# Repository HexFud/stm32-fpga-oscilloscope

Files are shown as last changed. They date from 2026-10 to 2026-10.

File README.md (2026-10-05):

# stm32-fpga-oscilloscope
I created a 1-Channel 20MHz 100MS/s Mixed-Signal Digital Storage Oscilloscope on a custom 4-layer PCB. Powered by STM32H7, Lattice iCE40 FPGA, and USB-C from scratch!

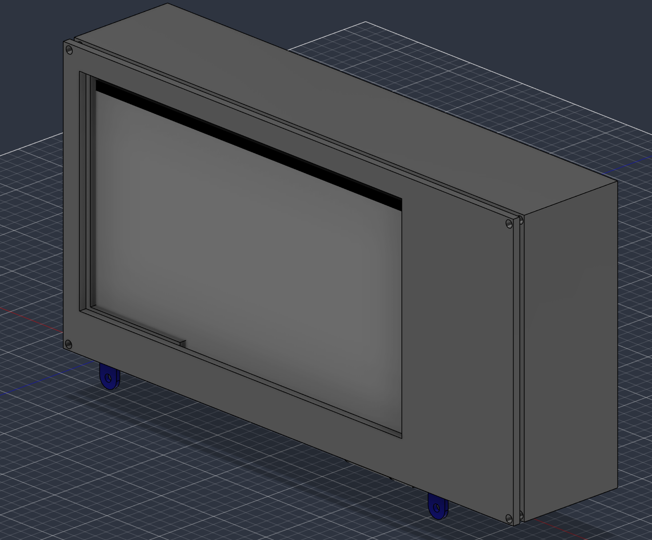
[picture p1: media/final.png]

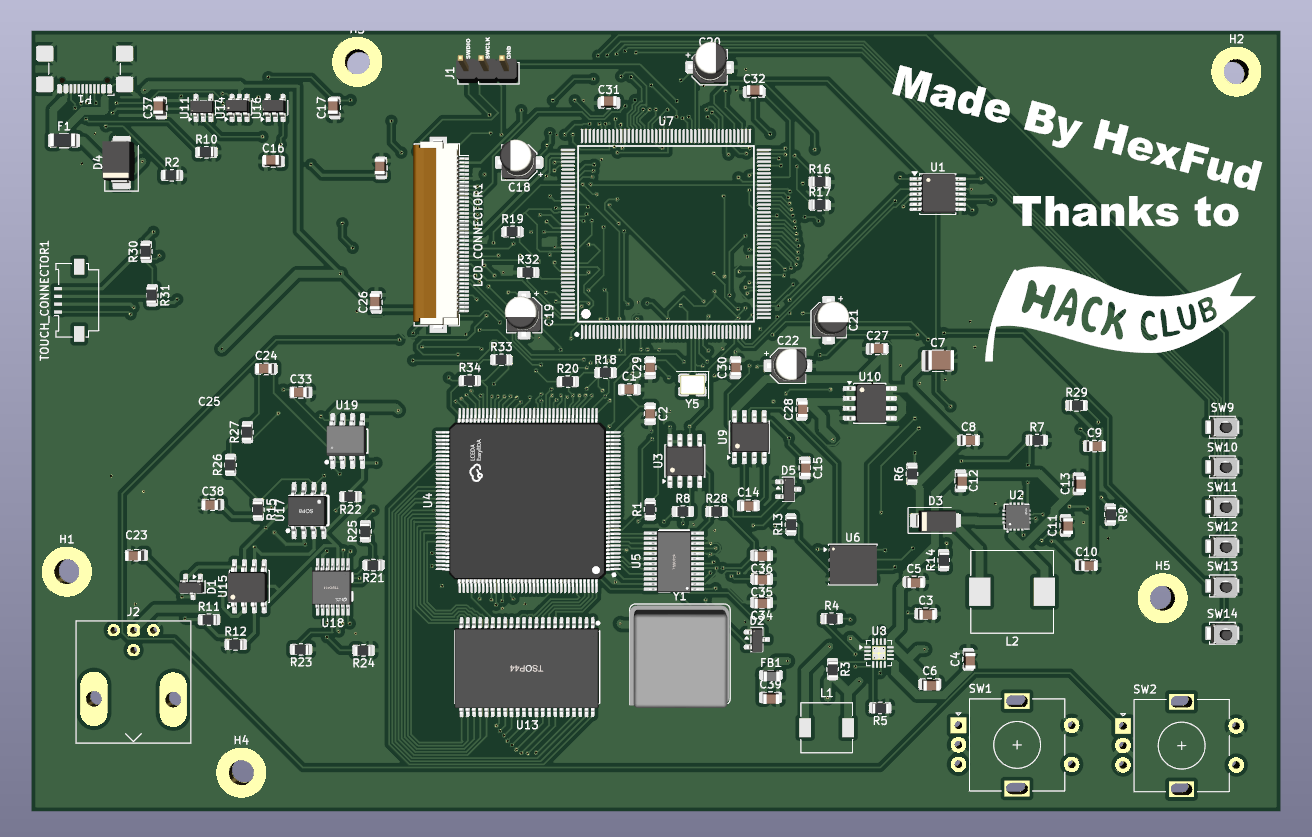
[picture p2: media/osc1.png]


## Project overview

The project is made of three parts that were designed together, because each one constrains the others: the PCB decides what the firmware can do, and the heat generated on the PCB decides how the enclosure is built.

| Part | What it covers | Tools |
| :--- | :--- | :--- |
| **PCB** | Schematic and 4-layer layout (see [Schematic and Routing](#schematic-and-routing) and [How this was made](#how-this-was-made)) | KiCad |
| **Firmware** | Acquisition, trigger, signal processing, waveform rendering and UI (see [Firmware](#firmware) and [Firmware architecture](#firmware-architecture)) | STM32CubeIDE, STM32 HAL |
| **CAD** | 3D-printable enclosure (see [Enclosure (CAD)](#enclosure-cad)) | **TODO:** CAD software |

## Schematic and Routing

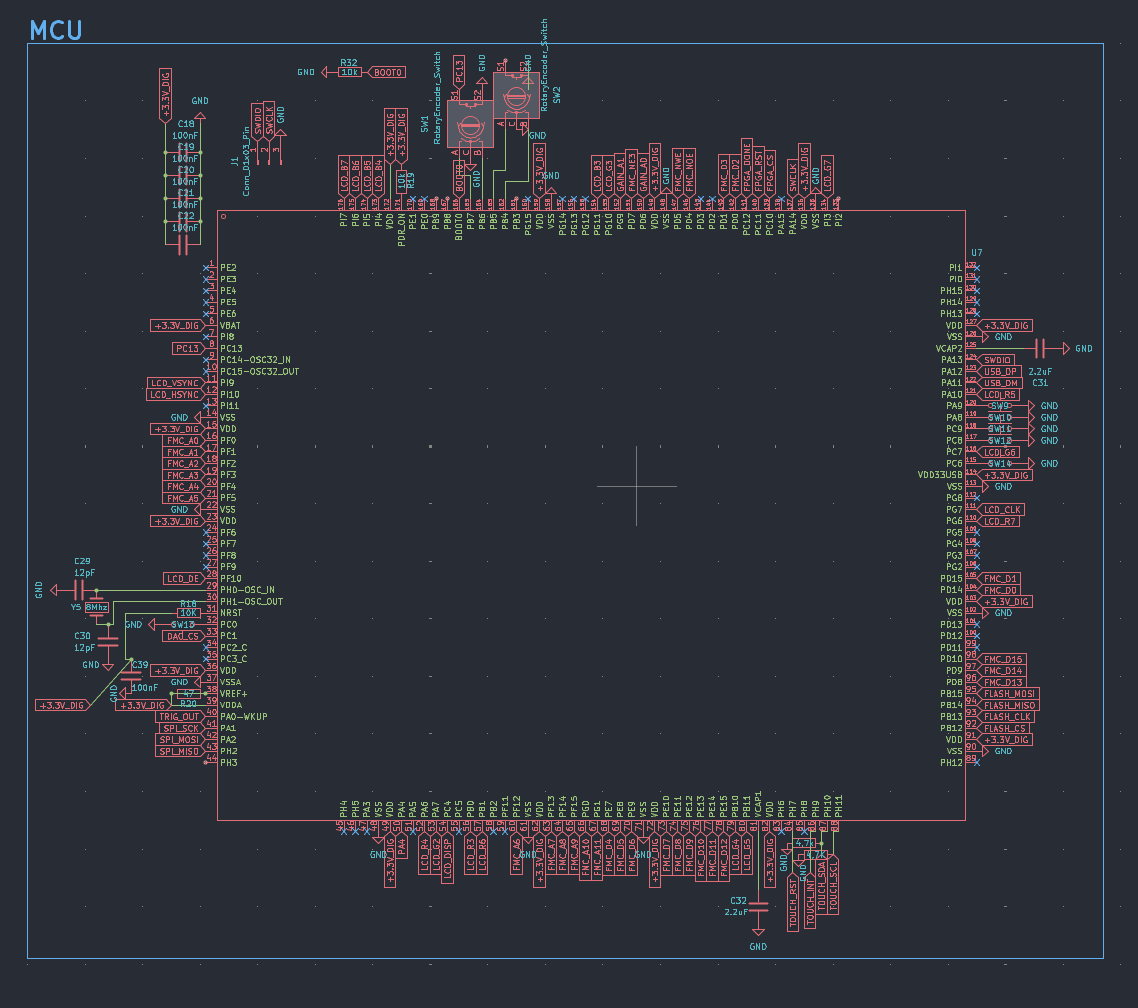
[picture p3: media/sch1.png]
sch1

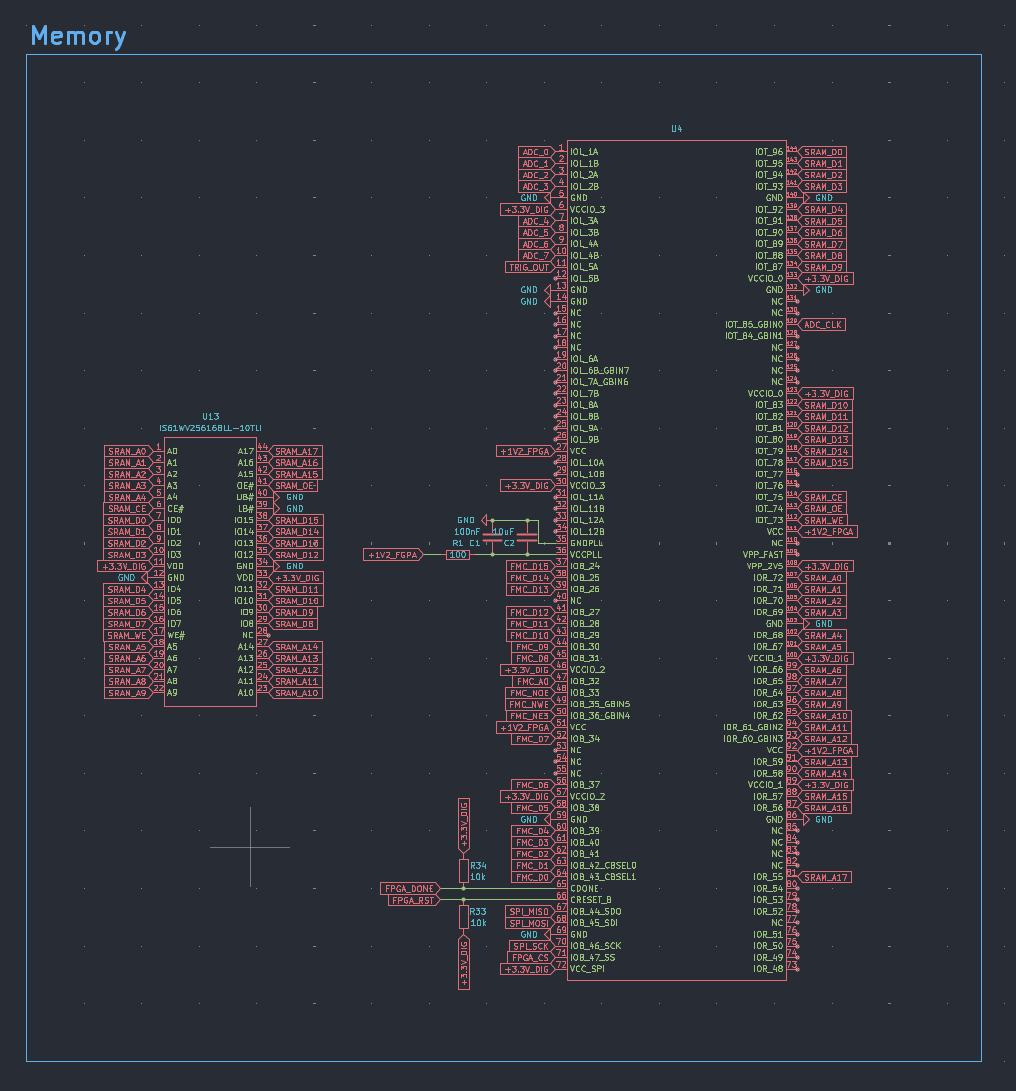
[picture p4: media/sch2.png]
sch2

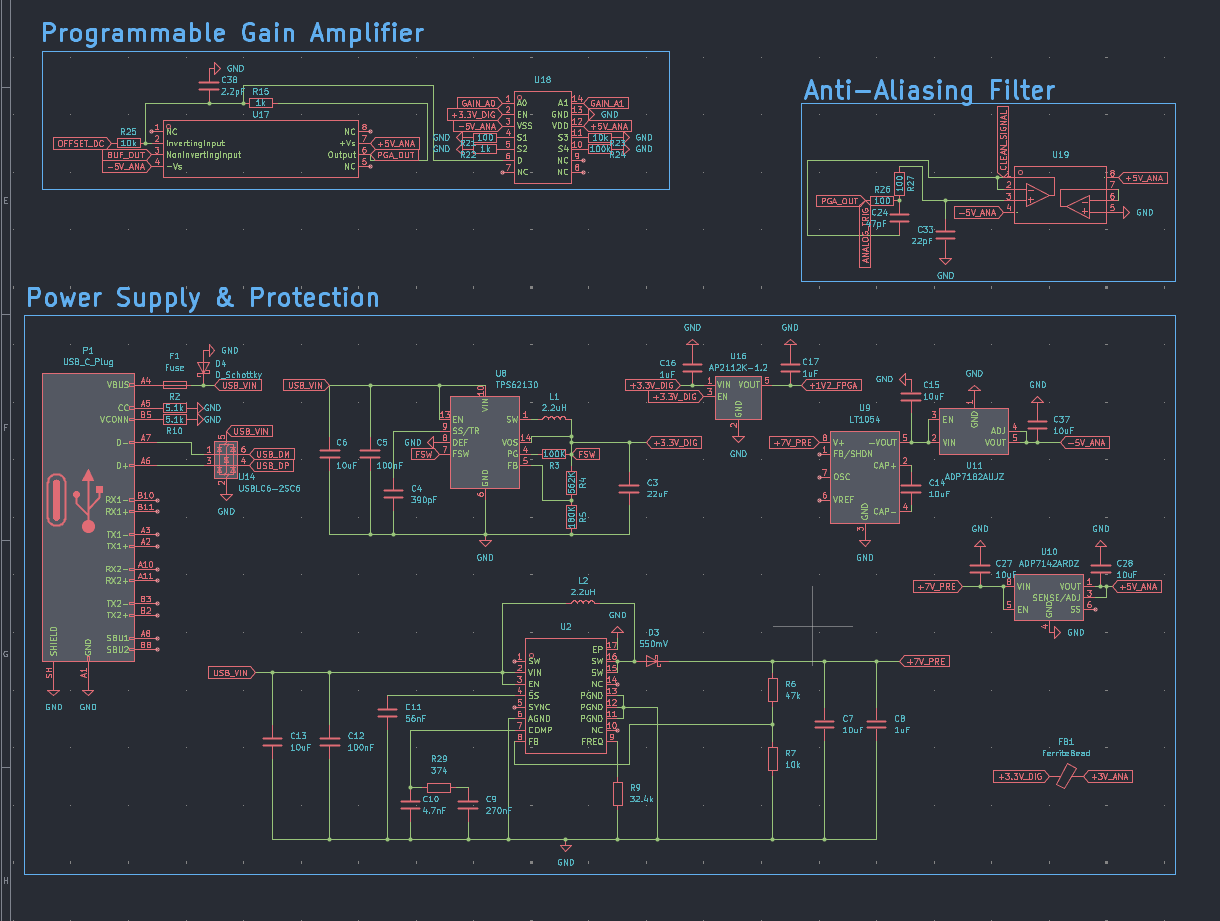
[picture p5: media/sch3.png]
sch3

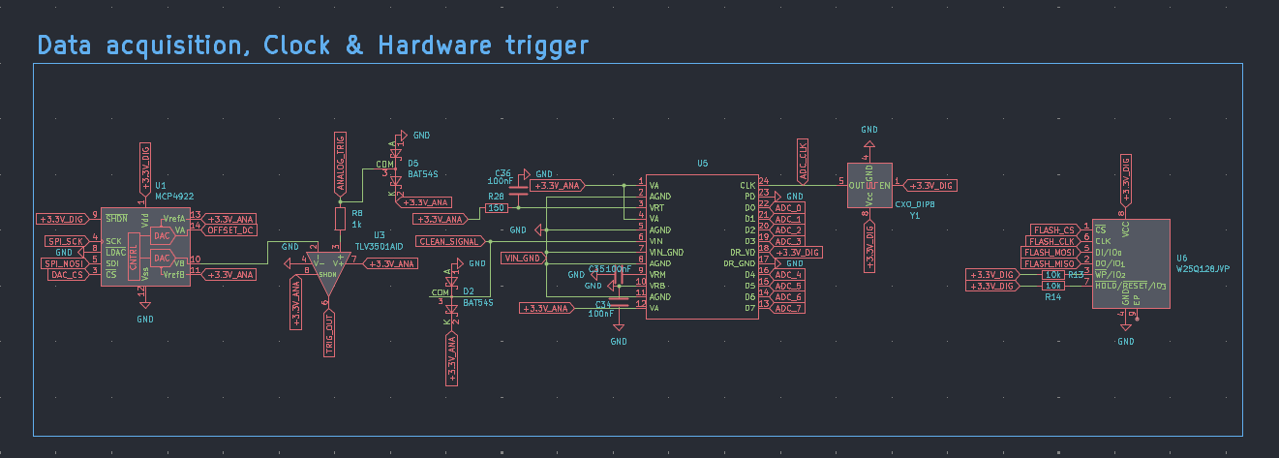
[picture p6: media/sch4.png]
sch4

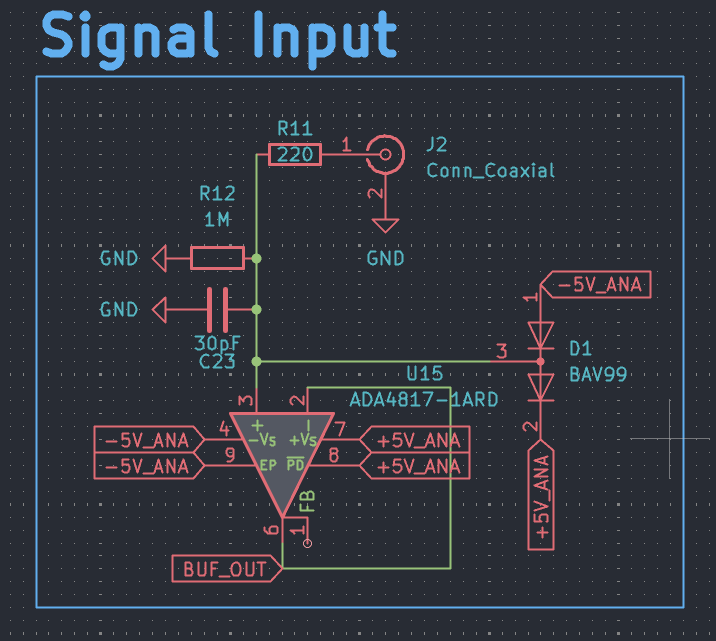
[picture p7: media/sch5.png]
sch5


## How this was made

I have designed the PCB starting from an STM32H7 microcontroller because of its support for external SRAM and it can directly control the main 7 Inch display with high speed transmission data. The entire board runs using a single 5V usb-C connection and then internally this becomes 3.3V, 1.2V and ±5V. The board includes connections for:
- A standard BNC input for oscilloscope probes (1MΩ impedance)
- 2 Rotary encoders and 6 tactile buttons for UI navigation
- A 40-pin FPC socket for an RGB LCD display with a dedicated capacitive touch connector.

## Specifications

| Parameter | Value |
| :--- | :--- |
| Channels | 1 analog |
| Analog bandwidth | 20 MHz |
| Sample rate | 100 MS/s |
| Input | BNC, 1 MΩ, x1 / x10 probes |
| Processing | STM32H7 + Lattice iCE40 FPGA |
| Display | 7" 800x480 RGB LCD, capacitive touch |
| User input | 2 rotary encoders, 6 buttons, touchscreen |
| Power / data | USB-C, 5 V |
| PCB | Custom 4-layer |

## Firmware
The firmware runs on the STM32H7 and is built with STM32CubeIDE and the STM32 HAL. It is responsible for acquisition control, trigger handling, signal processing, rendering the waveform and handling the user interface.

## Display and UI

- Waveform area with a graticule (grid) and a measurement/status bar
- Frame buffer in memory, redrawn on every new acquisition **TODO**
- Controls: one encoder for time base, one for volts/div, buttons for run/stop, single, trigger mode, etc.
- Touchscreen for menus and cursors **TODO**

## Firmware architecture

### Toolchain

| Item | Value |
| :--- | :--- |
| IDE | STM32CubeIDE |
| Drivers | STM32 HAL |
| Language | C |
| Programmer | ST-Link V2 over SWD (J1) |
| Flashing tool | STM32CubeProgrammer |

### Modules

The firmware is organised in layers, from the hardware up to the user interface:

| Layer | Module | Responsibility |
| :--- | :--- | :--- |
| Drivers | Display | Drives the 800x480 RGB panel from a frame buffer |
| Drivers | External memory | Initialises and accesses the external SRAM |
| Drivers | Touch | Reads touch events from the capacitive touch controller |
| Drivers | Input | Reads the 2 encoders and 6 buttons |
| Drivers | FPGA link | Configures the FPGA and transfers captured samples |
| Core | Acquisition | Arms the capture, manages run / stop / single modes and the time base |
| Core | Trigger | Trigger configuration (source, level, slope, mode) |
| Core | Processing | Scaling by volts/div and time/div, measurements |
| UI | Renderer | Draws the graticule, the waveform and the measurement/status bar |
| UI | Controls | Maps encoders, buttons and touch to oscilloscope settings |

### Data flow

1. The ADC samples the input signal and the FPGA captures the samples and evaluates the trigger condition.
2. When a trigger fires, the captured record is transferred to the STM32H7 and stored in memory.
3. The processing stage scales the record to the current volts/div and time/div settings.
4. The renderer draws the graticule and the waveform into the frame buffer, and the display peripheral shows it on screen.
5. Encoder, button and touch events update the settings, and the cycle restarts.

### Testing and debugging

**TODO**

## External connections

1. USB-C Power and Data (P1) this port powers the entire board and it is protected against ESD via a dedicated USBLC6-2SC6 chip
2. Signal Input (J2) It allows you to connect standard x1/x10 oscilloscope probes to measure
3. Programming Port (J1)  Has 3 pins dedicated to flashing and debugging the STM32 microcontroller

| Pin | Function | Where to connect (ST-Link) |
| :---: | :--- | :--- |
| **1** | `SWDIO` | ST-Link SWDIO |
| **2** | `SWCLK` | ST-Link SWCLK |
| **3** | `GND` | ST-Link GND |

## How to flash the firmware

My project uses an STM32H7 chip. To flash the firmware you need an ST-LINK V2 where you need to wire up the correct cable from the usb to the board (J1 connector) and download the free software [STM32CubeProgrammer](https://www.st.com/content/st_com/en/stm32cubeprogrammer.html) and you simply need to upload the firmware.

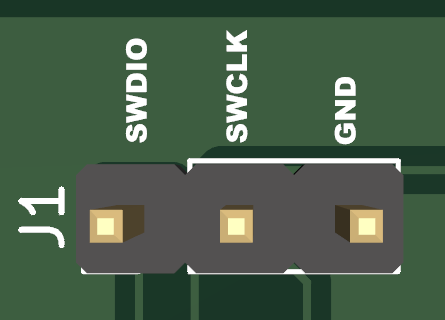
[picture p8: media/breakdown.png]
Connector pinout


Steps to reproduce (note that you need to do both):

In STM32CubeIDE:

1. Install STM32CubeIDE
2. Open the project folder inside the IDE
3. Let the IDE resolve the HAL dependencies
4. Go to Project -> Build All to compile the code
5. Wait for the compilation to finish and locate the generated `.bin` or `.elf` file in the `Debug` folder.

In STM32CubeProgrammer:

1. Install the software from the link above
2. Insert the ST-Link V2 USB into the pc
3. Connect the pins explained above (you can power the board via the USB-C port while flashing)
4. In STM32CubeProgrammer ensure that ST-LINK is selected and click connect
5. Go in the erasing & programming tab and select the previously exported `.bin` file
6. Click start programming and if everything went right you'll see Download verified successfully

## Enclosure (CAD)

The enclosure is designed to be 3D printed and to hold the PCB and the 7" display in a single compact unit.

This was designed to:
- Hold the PCB and the 7" display in one unit, with the display window aligned to the active area of the panel
- Expose the BNC input (J2), the USB-C port (P1) and the programming header (J1) without opening the case
- Give access to the 2 rotary encoders and the 6 buttons from the front
- Manage heat: the linear regulators (LDOs) and the FPGA warm up during continuous high-speed sampling, so the enclosure must not trap heat or soften (see the filament recommendation below)

## Filament reccomendation

Because linear regulators (LDOs) and the FPGA generate heat during continuous high-speed sampling, I strongly reccomend to use filaments like PETG, ABS or ASA instead of standard PLA ensuring the plastic won't soften, warp or melt during intensive usage.

## Bill of materials

The full list is in [`bom.csv`](bom.csv). The total is **614.79 USD**. It includes the PCB manufacturing, the 7" display and the parts that are not sourced from LCSC.

## ⚠️⚠️ Safety advice ⚠️⚠️

This project includes experimental software, hardware designs, and assembly documentation are still under development and may contain bugs, errors, or incomplete features. By using, building, or modifying this project, you acknowledge that:

1. You use this project entirely at your own risk
2. You are solely responsible for safe assembly, testing, and operation
3. The autor isn't responsible for any type of damage, injury or loss to people or the machine itself

By proceeding, you accept all risks and agree to these conditions. If you do not acknowledge these risks and conditions, please do not use or build this project.

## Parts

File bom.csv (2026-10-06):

Mrf# | Mfr. | Order Qty. | Unit Price(USD) | Ext.Price(USD) | LCSC# | Package | Description | Product Link
STM32H743IIT6 | ST | 2 | 11.1993 | 22.40 | C89597 | LQFP-176(24x24) | ARM Cortex-M7 32 Bit 480MHz LQFP-176 Microcontrollers | https://www.lcsc.com/product-detail/C89597.html
ICE40HX4K-TQ144 | Lattice | 2 | 17.1574 | 34.31 | C1521989 | TQFP-144(20x20) | 107 I/O 3520 LUTs TQFP-144 FPGAs | https://www.lcsc.com/product-detail/C1521989.html
ADC08100CIMTCX/NOPB | TI | 2 | 4.5676 | 9.14 | C701581 | TSSOP-24 | Parallel port 2.7V~3.6V 100MSPS TSSOP-24 ADC | https://www.lcsc.com/product-detail/C701581.html
IS61WV25616BLL-10TLI | ISSI | 2 | 8.4928 | 16.99 | C53825 | TSOPII-44 | 4Mbit (256Kx16) High Speed Async SRAM | https://www.lcsc.com/product-detail/C53825.html
W25Q128JVPIQ | Winbond | 2 | 3.2876 | 6.58 | C190862 | WSON-8-EP(5x6) | 128Mbit SPI 133MHz Flash Memory | https://www.lcsc.com/product-detail/C190862.html
MCP4922-E/ST | MICROCHIP | 2 | 2.6340 | 5.27 | C637136 | TSSOP-14 | Dual 12-Bit SPI DAC | https://www.lcsc.com/product-detail/C637136.html
TLV3501AIDR | TI | 2 | 3.5022 | 7.00 | C43484 | SOP-8 | 4.5ns Rail-to-Rail High Speed Comparator | https://www.lcsc.com/product-detail/C43484.html
ADA4817-1ARDZ-R7 | ADI | 2 | 9.9745 | 19.95 | C207502 | SOIC-8-EP | 1 GHz FastFET Low Noise Op-Amp | https://www.lcsc.com/product-detail/C207502.html
OPA820IDR | TI | 2 | 3.2908 | 6.58 | C2878255 | SOIC-8 | 280MHz Wideband Voltage Feedback Op-Amp | https://www.lcsc.com/product-detail/C2878255.html
TMUX6104PWR | TI | 2 | 4.9362 | 9.87 | C2673388 | TSSOP-14 | 1 Circuit IC SWITCH 4:1 125Ω TSSOP-14 (ADG1204 drop-in) | https://www.lcsc.com/product-detail/C2673388.html
AD8058ARZ | ADI | 2 | 7.9267 | 15.85 | C208568 | SOIC-8 | Dual 325 MHz Voltage Feedback Amplifier | https://www.lcsc.com/product-detail/C208568.html
TPS62130RGTR | TI | 2 | 1.3205 | 2.64 | C43590 | QFN-16-EP(3x3) | 3A Step-Down DC-DC Converter QFN-16 | https://www.lcsc.com/product-detail/C43590.html
TPS55340QRTERQ1 | TI | 2 | 5.1000 | 10.20 | C2070860 | WQFN-16-EP(3x3) | 5.25A Boost Switching Regulator WQFN-16 | https://www.lcsc.com/product-detail/C2070860.html
LT1054IP | TI | 1 | 6.5964 | 6.60 | C2878994 | PDIP-8 | Switched-Capacitor Inverter 100mA PDIP-8 | https://www.lcsc.com/product-detail/C2878994.html
ADP7142ARDZ | ADI | 2 | 7.4796 | 14.96 | C3745280 | SOIC-8-EP | 200mA Low Noise Linear LDO Regulator | https://www.lcsc.com/product-detail/C3745280.html
ADP7182AUJZ-R7 | ADI | 2 | 3.5612 | 7.12 | C514358 | TSOT-23-5 | 200mA Low Noise Negative LDO Regulator | https://www.lcsc.com/product-detail/C514358.html
AP2112K-1.2TRG1 | DIODES | 50 | 0.2870 | 14.35 | C460310 | SOT-25 | 1.2V 600mA Fixed LDO SOT-25 | https://www.lcsc.com/product-detail/C460310.html
USBLC6-2SC6 | ST | 50 | 0.1374 | 6.87 | C7519 | SOT-23-6L | Low Capacitance ESD Protection Diode SOT-23-6 | https://www.lcsc.com/product-detail/C7519.html
BAV99 | JSMSEMI | 50 | 0.0093 | 0.47 | C916421 | SOT-23 | Dual High-Speed Switching Diode SOT-23 | https://www.lcsc.com/product-detail/C916421.html
BAT54S | JSMSEMI | 50 | 0.0129 | 0.65 | C916425 | SOT-23 | Dual Schottky Barrier Diode SOT-23 | https://www.lcsc.com/product-detail/C916425.html
SS34 | MDD | 60 | 0.0351 | 2.11 | C8678 | SMA(DO-214AC) | Schottky Diode 40V 3A SMA | https://www.lcsc.com/product-detail/C8678.html
SS24 | YANGJIE | 50 | 0.0771 | 3.86 | C2845097 | SMB(DO-214AA) | Schottky Diode 40V 2A SMB | https://www.lcsc.com/product-detail/C2845097.html
BSMD1206C-1200T | BHFUSE | 50 | 0.0648 | 3.24 | C41367223 | 1206 | 2A 72V Fast Surface Mount Fuse 1206 | https://www.lcsc.com/product-detail/C41367223.html
SX3M100.000B20F30TNN | SCTF | 50 | 0.4796 | 23.98 | C5179979 | SMD3225-4P | Oscillator 100MHz ±20ppm CMOS 3.3V SMD3225 | https://www.lcsc.com/product-detail/C5179979.html
X32258MOB4SI | YXC | 50 | 0.1540 | 7.70 | C2682775 | SMD3225-4P | Crystal 8MHz ±10ppm 12pF SMD3225 | https://www.lcsc.com/product-detail/C2682775.html
APS0630M2R2A | Coilank | 50 | 0.0972 | 4.86 | C47327201 | SMD,7.7x6.6mm | 2.2uH 9.6A Fixed Power Inductor | https://www.lcsc.com/product-detail/C47327201.html
SRG1040-2R2-M | JIERR | 50 | 0.1564 | 7.82 | C53463002 | SMD,11.5x10.5mm | 2.2uH 14A Molded Power Inductor | https://www.lcsc.com/product-detail/C53463002.html
BLM21PG601SN1D | muRata | 50 | 0.0601 | 3.01 | C41556732 | 0805 | 600Ω@100MHz Ferrite Bead 0805 | https://www.lcsc.com/product-detail/C41556732.html
CC0805CRNPO9BN2R2 | YAGEO | 100 | 0.0163 | 1.63 | C519933 | 0805 | 2.2pF 50V Ceramic Capacitor NP0 0805 | https://www.lcsc.com/product-detail/C519933.html
CC0805JRNPO9BN120 | YAGEO | 100 | 0.0071 | 0.71 | C107108 | 0805 | 12pF 50V Ceramic Capacitor NP0 0805 | https://www.lcsc.com/product-detail/C107108.html
CL21C220JBANNNC | Samsung | 50 | 0.0123 | 0.62 | C1804 | 0805 | 22pF 50V Ceramic Capacitor C0G 0805 | https://www.lcsc.com/product-detail/C1804.html
0805CG300J500NT | FH | 100 | 0.0052 | 0.52 | C43094 | 0805 | 30pF 50V Ceramic Capacitor C0G 0805 | https://www.lcsc.com/product-detail/C43094.html
CL21C470JBANNNC | Samsung | 100 | 0.0107 | 1.07 | C14857 | 0805 | 47pF 50V Ceramic Capacitor C0G 0805 | https://www.lcsc.com/product-detail/C14857.html
08055A391JAT2A | Kyocera AVX | 100 | 0.0416 | 4.16 | C2176641 | 0805 | 390pF 50V Ceramic Capacitor C0G 0805 | https://www.lcsc.com/product-detail/C2176641.html
CL21B472KBANNNC | Samsung | 50 | 0.0137 | 0.69 | C50131 | 0805 | 4.7nF 50V Ceramic Capacitor X7R 0805 | https://www.lcsc.com/product-detail/C50131.html
CC0805KRX7R9BB563 | YAGEO | 100 | 0.0112 | 1.12 | C107156 | 0805 | 56nF 50V Ceramic Capacitor X7R 0805 | https://www.lcsc.com/product-detail/C107156.html
CL21B104KBCNNNC | Samsung | 100 | 0.0151 | 1.51 | C1711 | 0805 | 100nF 50V Ceramic Capacitor X7R 0805 | https://www.lcsc.com/product-detail/C1711.html
CC0805KKX7R9BB274 | YAGEO | 100 | 0.0329 | 3.29 | C113845 | 0805 | 270nF 50V Ceramic Capacitor X7R 0805 | https://www.lcsc.com/product-detail/C113845.html
CL21B105KAFNNNE | Samsung | 100 | 0.0332 | 3.32 | C116352 | 0805 | 1uF 25V Ceramic Capacitor X7R 0805 | https://www.lcsc.com/product-detail/C116352.html
CL21B225KOFNNNE | Samsung | 100 | 0.0429 | 4.29 | C28234 | 0805 | 2.2uF 16V Ceramic Capacitor X7R 0805 | https://www.lcsc.com/product-detail/C28234.html
GRM21BR61H106KE43L | muRata | 20 | 0.2087 | 4.17 | C440198 | 0805 | 10uF 50V Ceramic Capacitor X5R 0805 | https://www.lcsc.com/product-detail/C440198.html
HGC1210R7106K500NSVK | Chinocera | 10 | 0.2103 | 2.10 | C7472976 | 1210 | 10uF 50V Ceramic Capacitor X7R 1210 | https://www.lcsc.com/product-detail/C7472976.html
CL21A226MOQNNNE | Samsung | 50 | 0.1059 | 5.30 | C98190 | 0805 | 22uF 16V Ceramic Capacitor X5R 0805 | https://www.lcsc.com/product-detail/C98190.html
RC0805FR-07100RL | YAGEO | 1100 | 0.0050 | 5.50 | C105577 | 0805 | 100Ω ±1% 125mW 0805 Resistor | https://www.lcsc.com/product-detail/C105577.html
0805W8F4700T5E | UNI-ROYAL | 100 | 0.0049 | 0.49 | C17710 | 0805 | 470Ω ±1% 125mW 0805 Resistor | https://www.lcsc.com/product-detail/C17710.html
0805W8F1500T5E | UNI-ROYAL | 100 | 0.0057 | 0.57 | C17471 | 0805 | 150Ω ±1% 125mW 0805 Resistor | https://www.lcsc.com/product-detail/C17471.html
0805W8F2200T5E | UNI-ROYAL | 100 | 0.0055 | 0.55 | C17557 | 0805 | 220Ω ±1% 125mW 0805 Resistor | https://www.lcsc.com/product-detail/C17557.html
FRC0805F3740TS | FOJAN | 100 | 0.0033 | 0.33 | C2999634 | 0805 | 374Ω ±1% 125mW 0805 Resistor | https://www.lcsc.com/product-detail/C2999634.html
0805W8F1001T5E | UNI-ROYAL | 100 | 0.0041 | 0.41 | C17513 | 0805 | 1kΩ ±1% 125mW 0805 Resistor | https://www.lcsc.com/product-detail/C17513.html
0805W8F4701T5E | UNI-ROYAL | 100 | 0.0051 | 0.51 | C17673 | 0805 | 4.7kΩ ±1% 125mW 0805 Resistor | https://www.lcsc.com/product-detail/C17673.html
0805W8F5101T5E | UNI-ROYAL | 100 | 0.0056 | 0.56 | C27834 | 0805 | 5.1kΩ ±1% 125mW 0805 Resistor | https://www.lcsc.com/product-detail/C27834.html
0805W8F1002T5E | UNI-ROYAL | 100 | 0.0034 | 0.34 | C17414 | 0805 | 10kΩ ±1% 125mW 0805 Resistor | https://www.lcsc.com/product-detail/C17414.html
0805W8F3242T5E | UNI-ROYAL | 100 | 0.0055 | 0.55 | C36938 | 0805 | 32.4kΩ ±1% 125mW 0805 Resistor | https://www.lcsc.com/product-detail/C36938.html
0805W8F4702T5E | UNI-ROYAL | 100 | 0.0068 | 0.68 | C17713 | 0805 | 47kΩ ±1% 125mW 0805 Resistor | https://www.lcsc.com/product-detail/C17713.html
0805W8F1003T5E | UNI-ROYAL | 100 | 0.0060 | 0.60 | C149504 | 0805 | 100kΩ ±1% 125mW 0805 Resistor | https://www.lcsc.com/product-detail/C149504.html
0805W8F1803T5E | UNI-ROYAL | 100 | 0.0039 | 0.39 | C17501 | 0805 | 180kΩ ±1% 125mW 0805 Resistor | https://www.lcsc.com/product-detail/C17501.html
CRCW0805562KFKEA | VISHAY | 10 | 0.0623 | 0.62 | C844213 | 0805 | 562kΩ ±1% 125mW 0805 Resistor | https://www.lcsc.com/product-detail/C844213.html
0805W8F1004T5E | UNI-ROYAL | 100 | 0.0044 | 0.44 | C17514 | 0805 | 1MΩ ±1% 125mW 0805 Resistor | https://www.lcsc.com/product-detail/C17514.html
FRC0805F47R0TS | FOJAN | 100 | 0.0034 | 0.34 | C2907268 | 0805 | 47Ω ±1% 125mW 0805 Resistor | https://www.lcsc.com/product-detail/C2907268.html
FRC0805F33R0TS | FOJAN | 100 | 0.0040 | 0.40 | C2907258 | 0805 | 33Ω ±1% 125mW 0805 Resistor | https://www.lcsc.com/product-detail/C2907258.html
FRC0805F3162TS | FOJAN | 100 | 0.0034 | 0.34 | C2930156 | 0805 | 31.6kΩ ±1% 125mW 0805 Resistor | https://www.lcsc.com/product-detail/C2930156.html
TYPE-C 16PIN 2MD(073) | SHOU HAN | 60 | 0.0750 | 4.50 | C2765186 | SMD | USB-C Receptacle 16 Position Surface Mount | https://www.lcsc.com/product-detail/C2765186.html
BNC-SMA-KJ-9C | cntitle | 2 | 3.6333 | 7.27 | C20415812 | Through Hole | 50Ω Through Hole Coaxial BNC Connector | https://www.lcsc.com/product-detail/C20415812.html
PZ254V-11-03P | XFCN | 50 | 0.0199 | 1.00 | C2937625 | Through Hole,P=2.54mm | Pin Header 3 Position 2.54mm Single Row | https://www.lcsc.com/product-detail/C2937625.html
KH-FG0.5-H2.0-40PIN | kinghelm | 23 | 0.1708 | 3.93 | C2797220 | SMD,P=0.5mm | FFC/FPC Connector 40 Position 0.5mm Bottom Contact | https://www.lcsc.com/product-detail/C2797220.html
2005280040 | MOLEX | 50 | 0.1505 | 7.53 | C563728 | SMD,P=1mm | FFC/FPC Connector 4 Position 1mm Bottom Contact | https://www.lcsc.com/product-detail/C563728.html
B3U-1000P | OMRON | 50 | 0.1479 | 7.40 | C231329 | SMD,3x2.5mm | Tactile Switch SPST 153gf 3x2.5mm SMD | https://www.lcsc.com/product-detail/C231329.html
KY-040 encoder | - | 2 | 0.8550 | 1.71 | - | Through-Hole | Rotary Encoder EC11 with Push Switch | https://it.aliexpress.com/item/1005008554510924.html
Original Waveshare 7Inch LCD (G) | Waveshare | 1 | 31.7900 | 31.79 | - | Module | 7 Inch 800x480 Capacitive Touch IPS Screen GT911 (29.30 €) | https://www.alibaba.com/product-detail/Original-Waveshare-7Inch-Capacitive-Touch-LCD_1601921857262.html
Magnifier | - | 1 | 94.3000 | 94.30 | - | Tool | Adjustable microscope/magnifier for electronics repair | https://www.amazon.it/Microscopio-Couleeur-Regolabili-Riparazioni-Elettroniche
PCB manufacturing | - | 1 | 100.0000 | 100.00 | - | Custom Board | Custom 4-Layer / 2-Layer PCB Prototype Batch Fabrication
TOTAL |  |  |  | 557.61

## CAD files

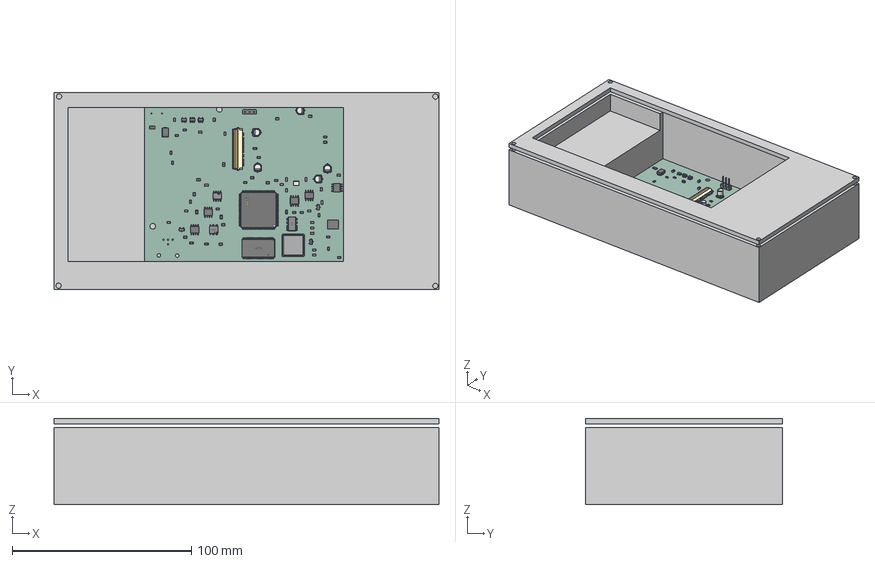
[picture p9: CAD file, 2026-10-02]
CAD/Oscilloscope.step
215.0 x 110.0 x 48.0 mm

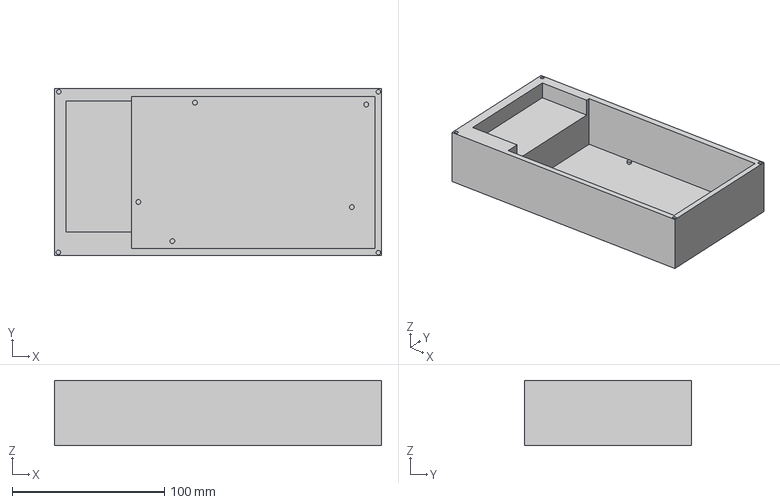
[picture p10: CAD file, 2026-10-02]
Production/Oscilloscope_back.step
215.0 x 110.0 x 43.0 mm

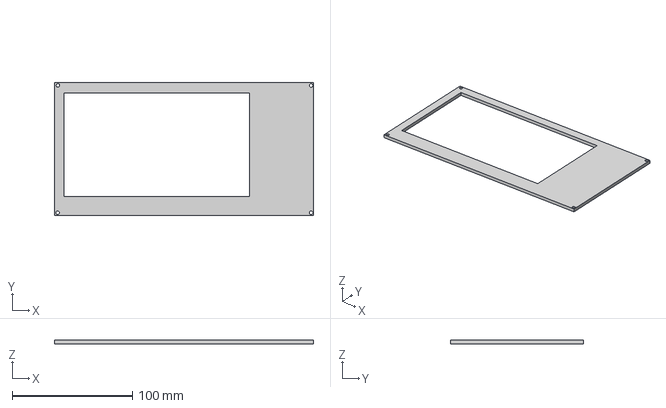
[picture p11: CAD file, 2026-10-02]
Production/Oscilloscope_front.step
215.0 x 110.0 x 3.00 mm

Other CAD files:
CAD/Hex_Oscilloscope.f3z

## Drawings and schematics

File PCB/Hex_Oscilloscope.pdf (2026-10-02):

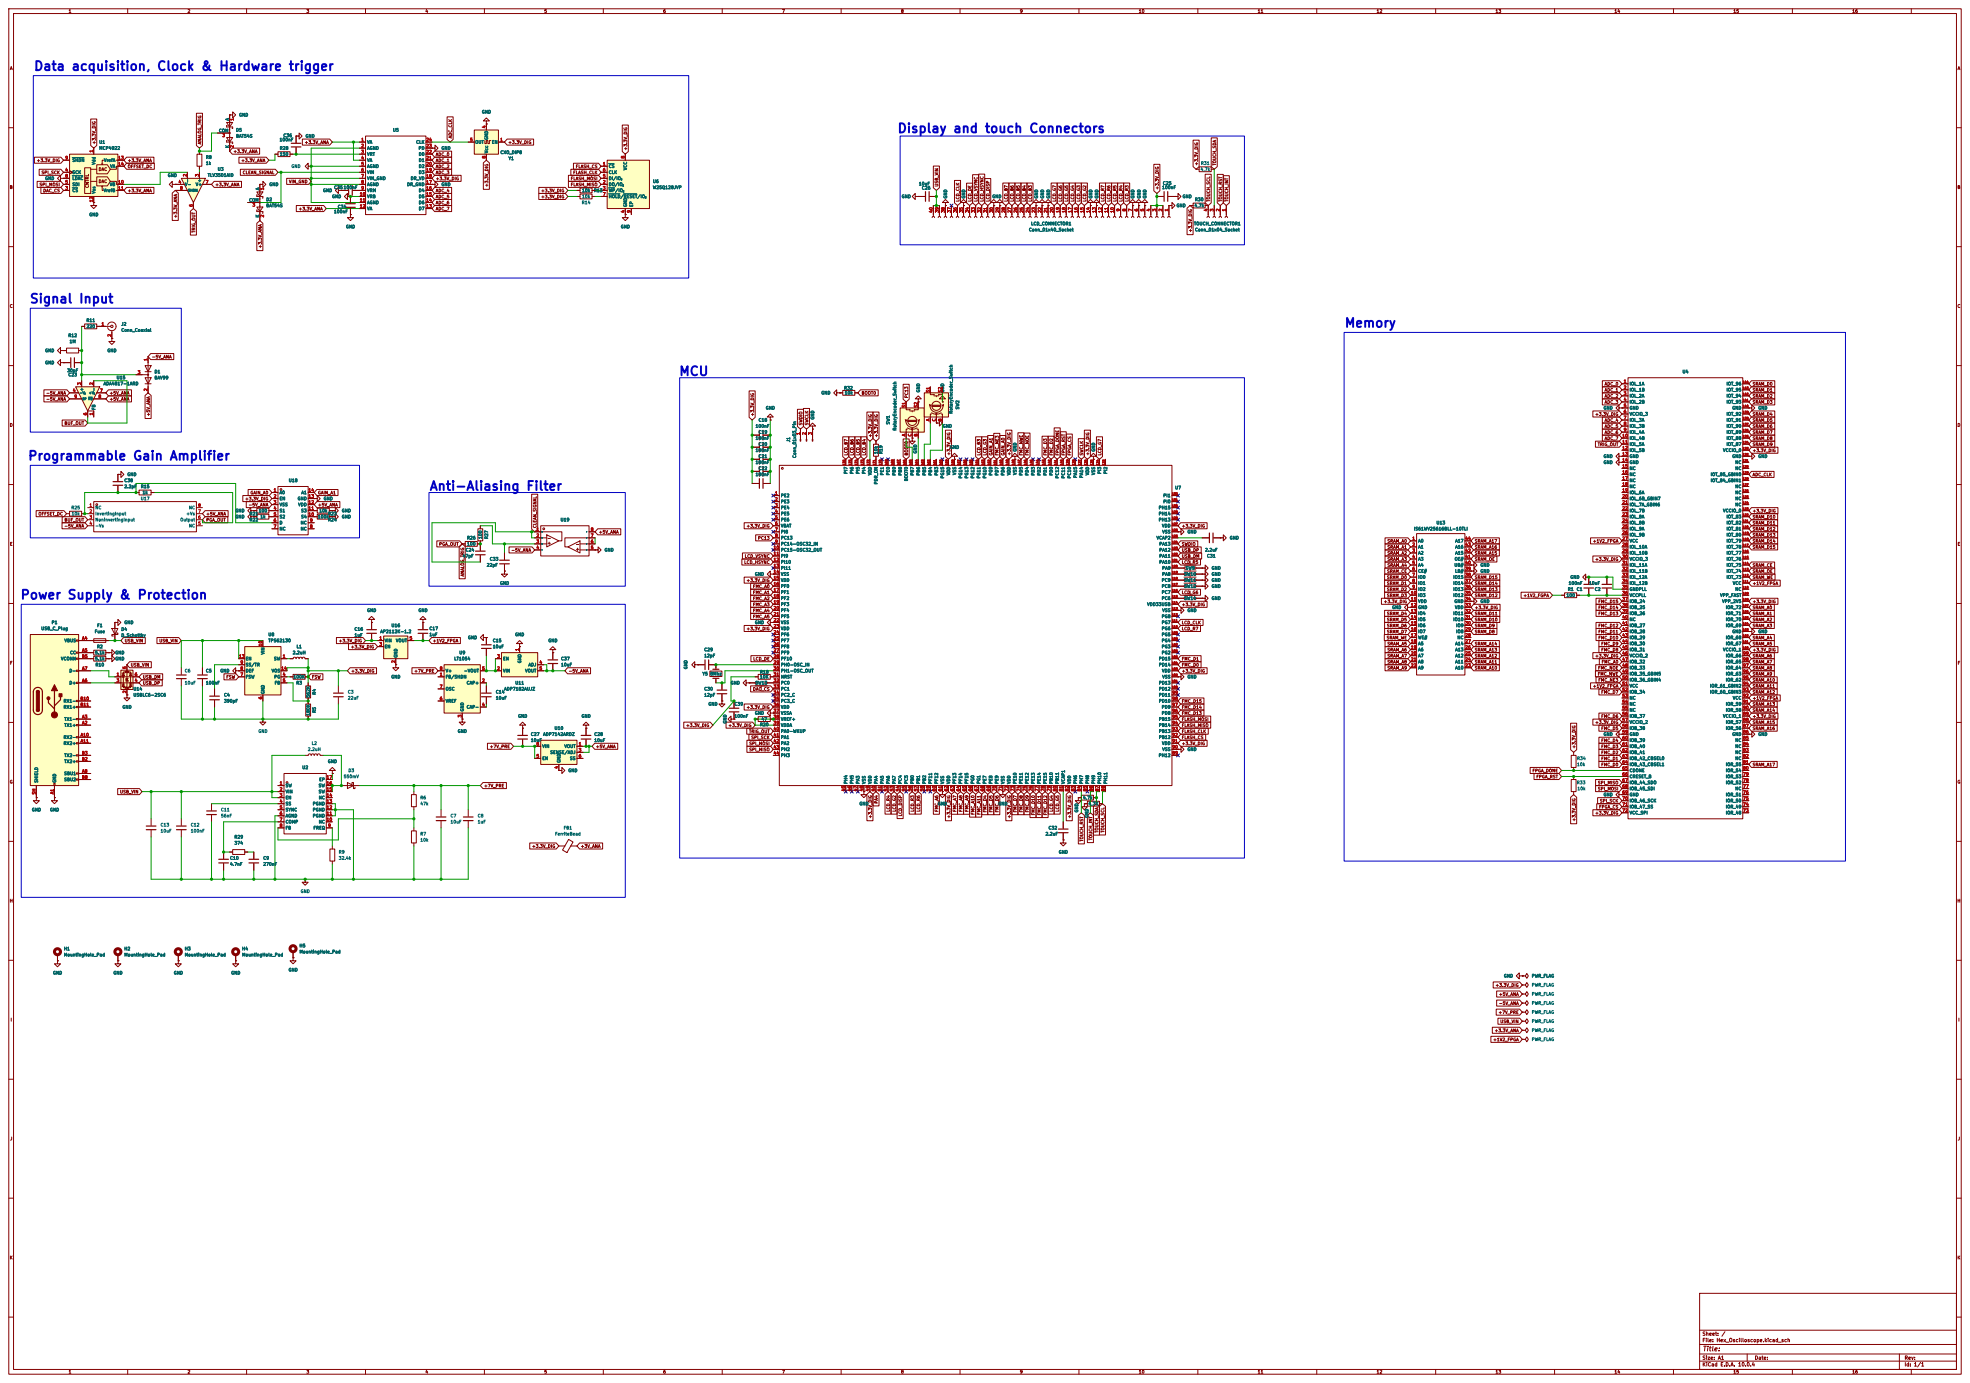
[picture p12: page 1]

Data acquisition, Clock & Hardware trigger

Display and touch Connectors

4 DI/IO0 5 CLK 6 HOLD/RESET/IO3 7 VCC

Size: A1 | Rev:
KiCad E.D.A. 10.0.4 | Id: 1/1

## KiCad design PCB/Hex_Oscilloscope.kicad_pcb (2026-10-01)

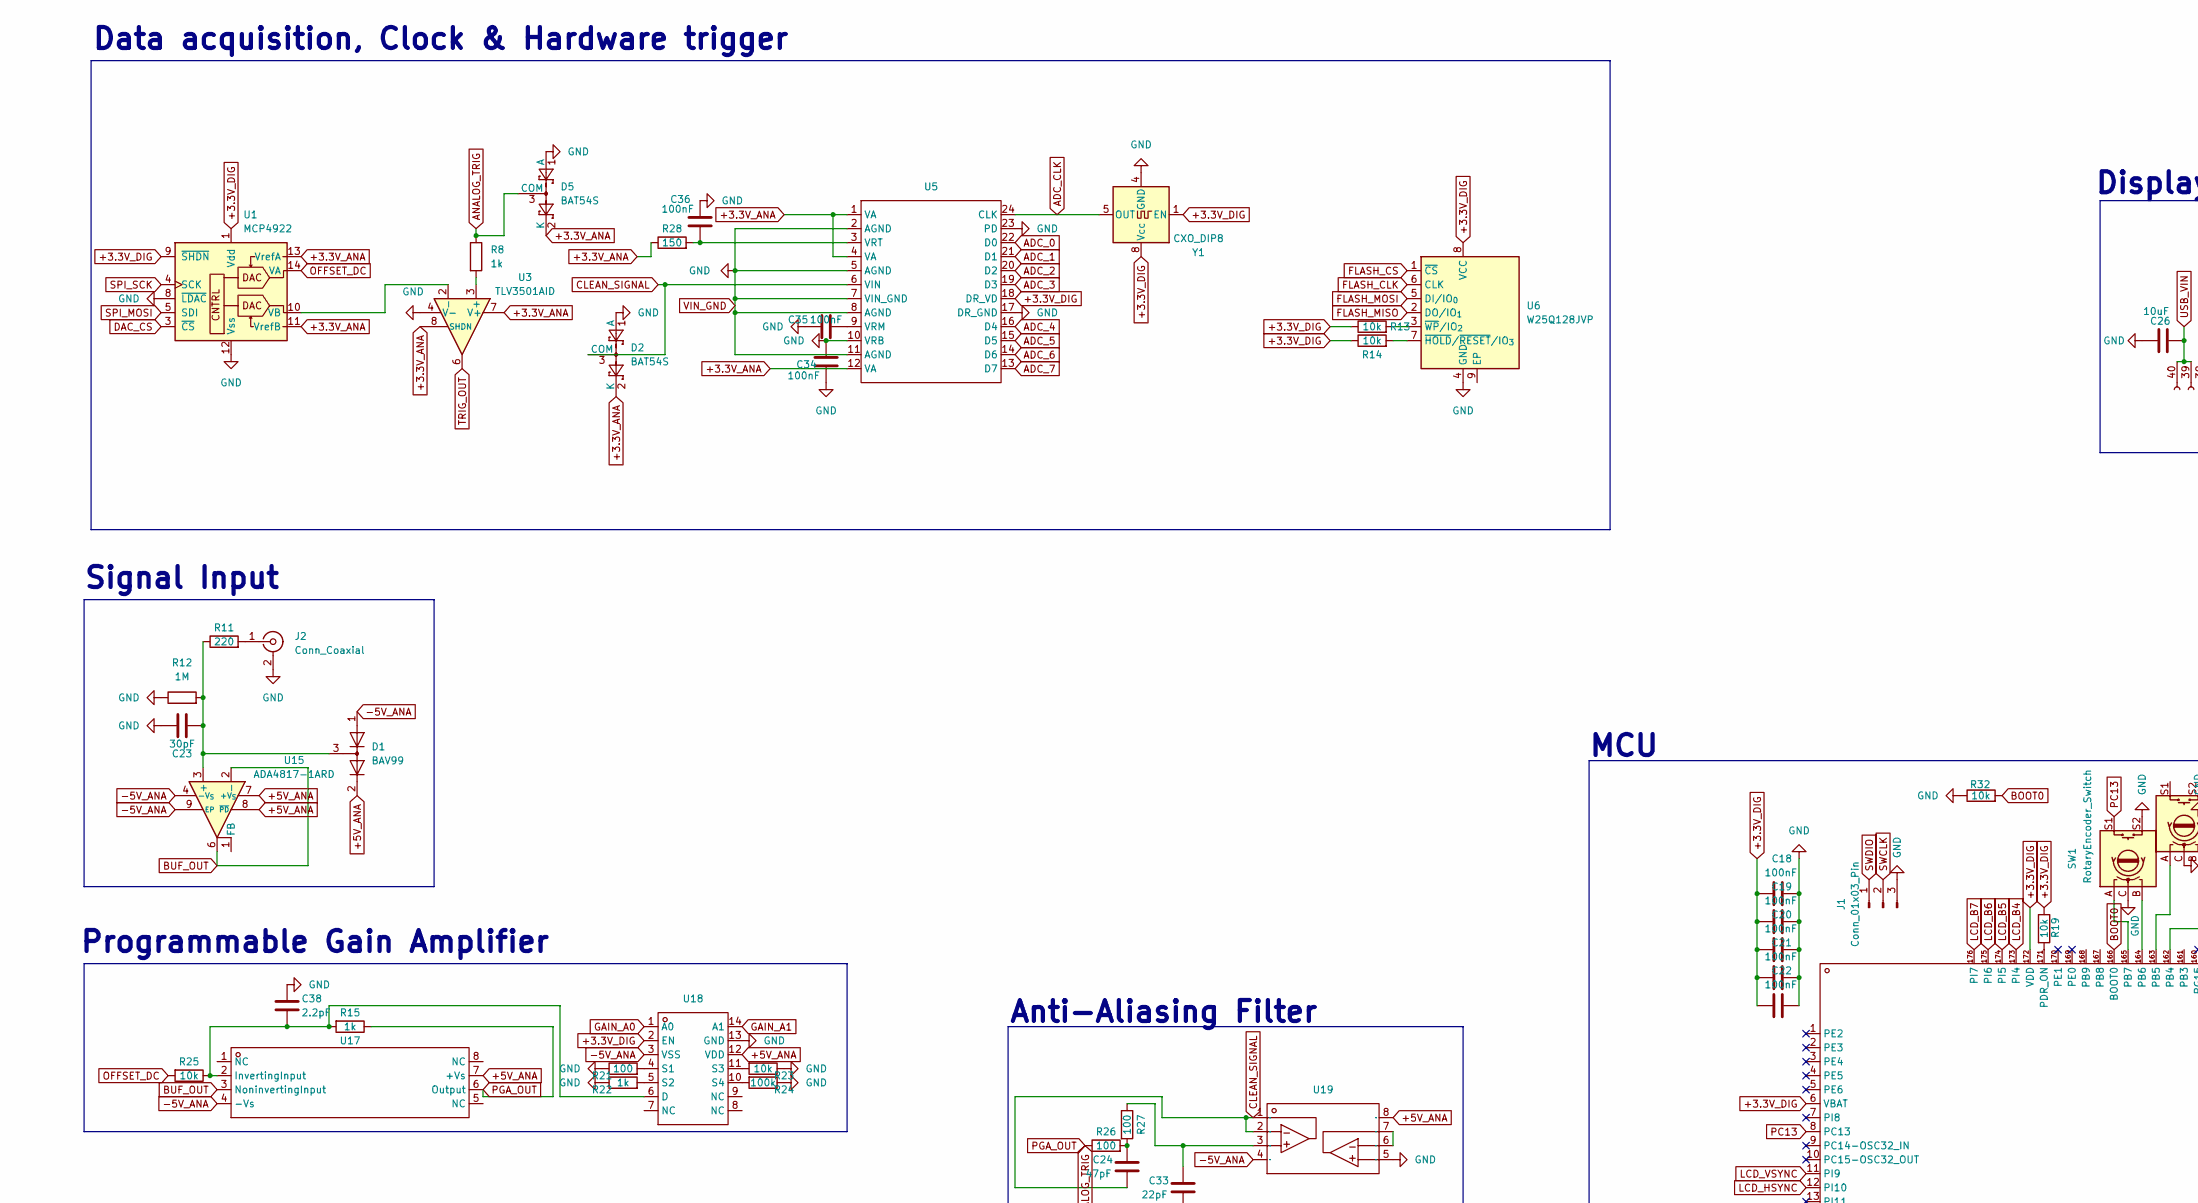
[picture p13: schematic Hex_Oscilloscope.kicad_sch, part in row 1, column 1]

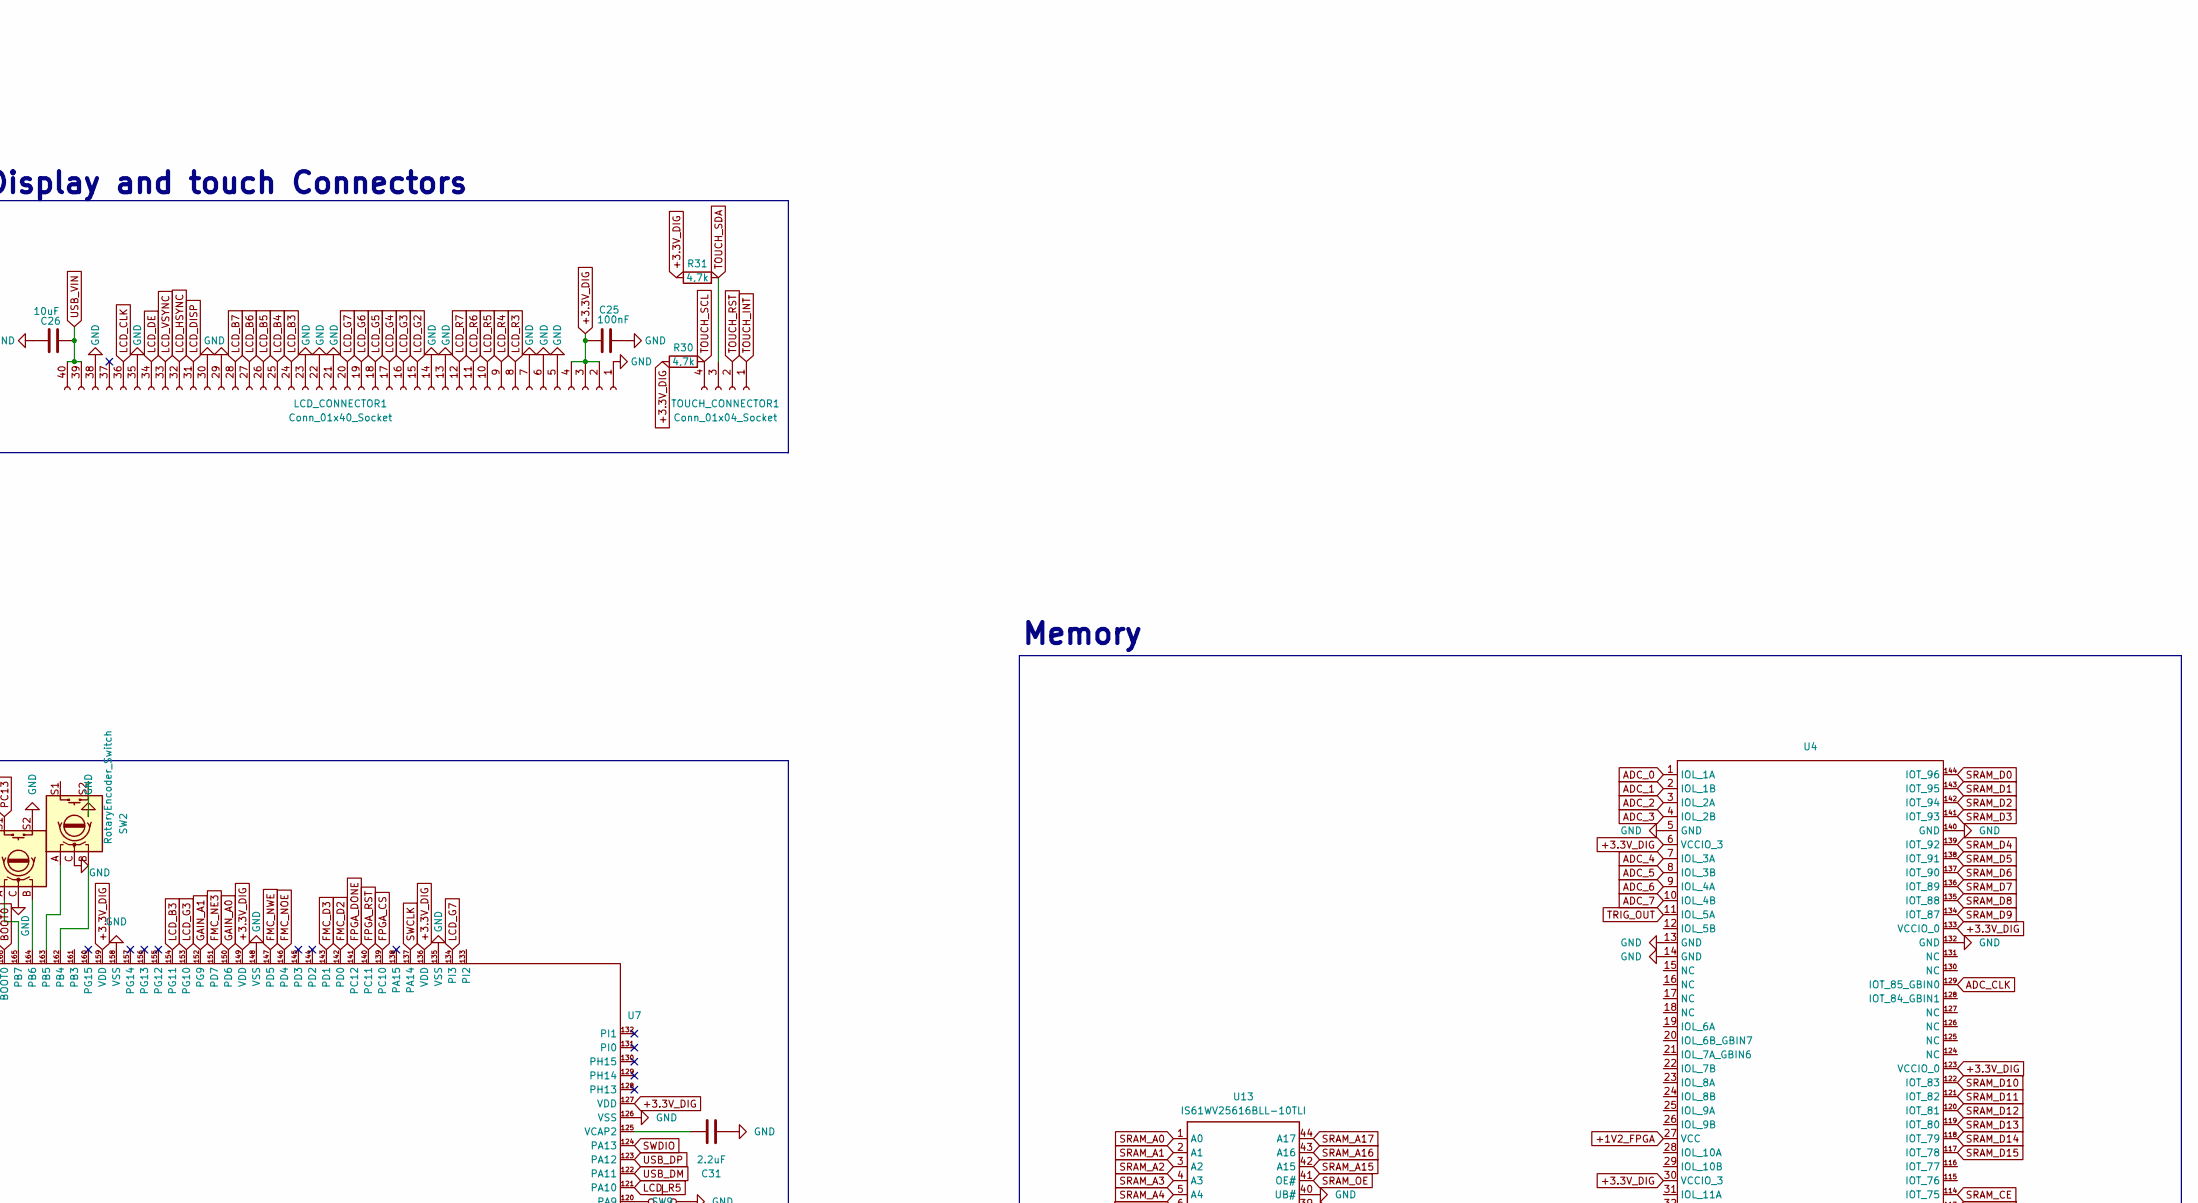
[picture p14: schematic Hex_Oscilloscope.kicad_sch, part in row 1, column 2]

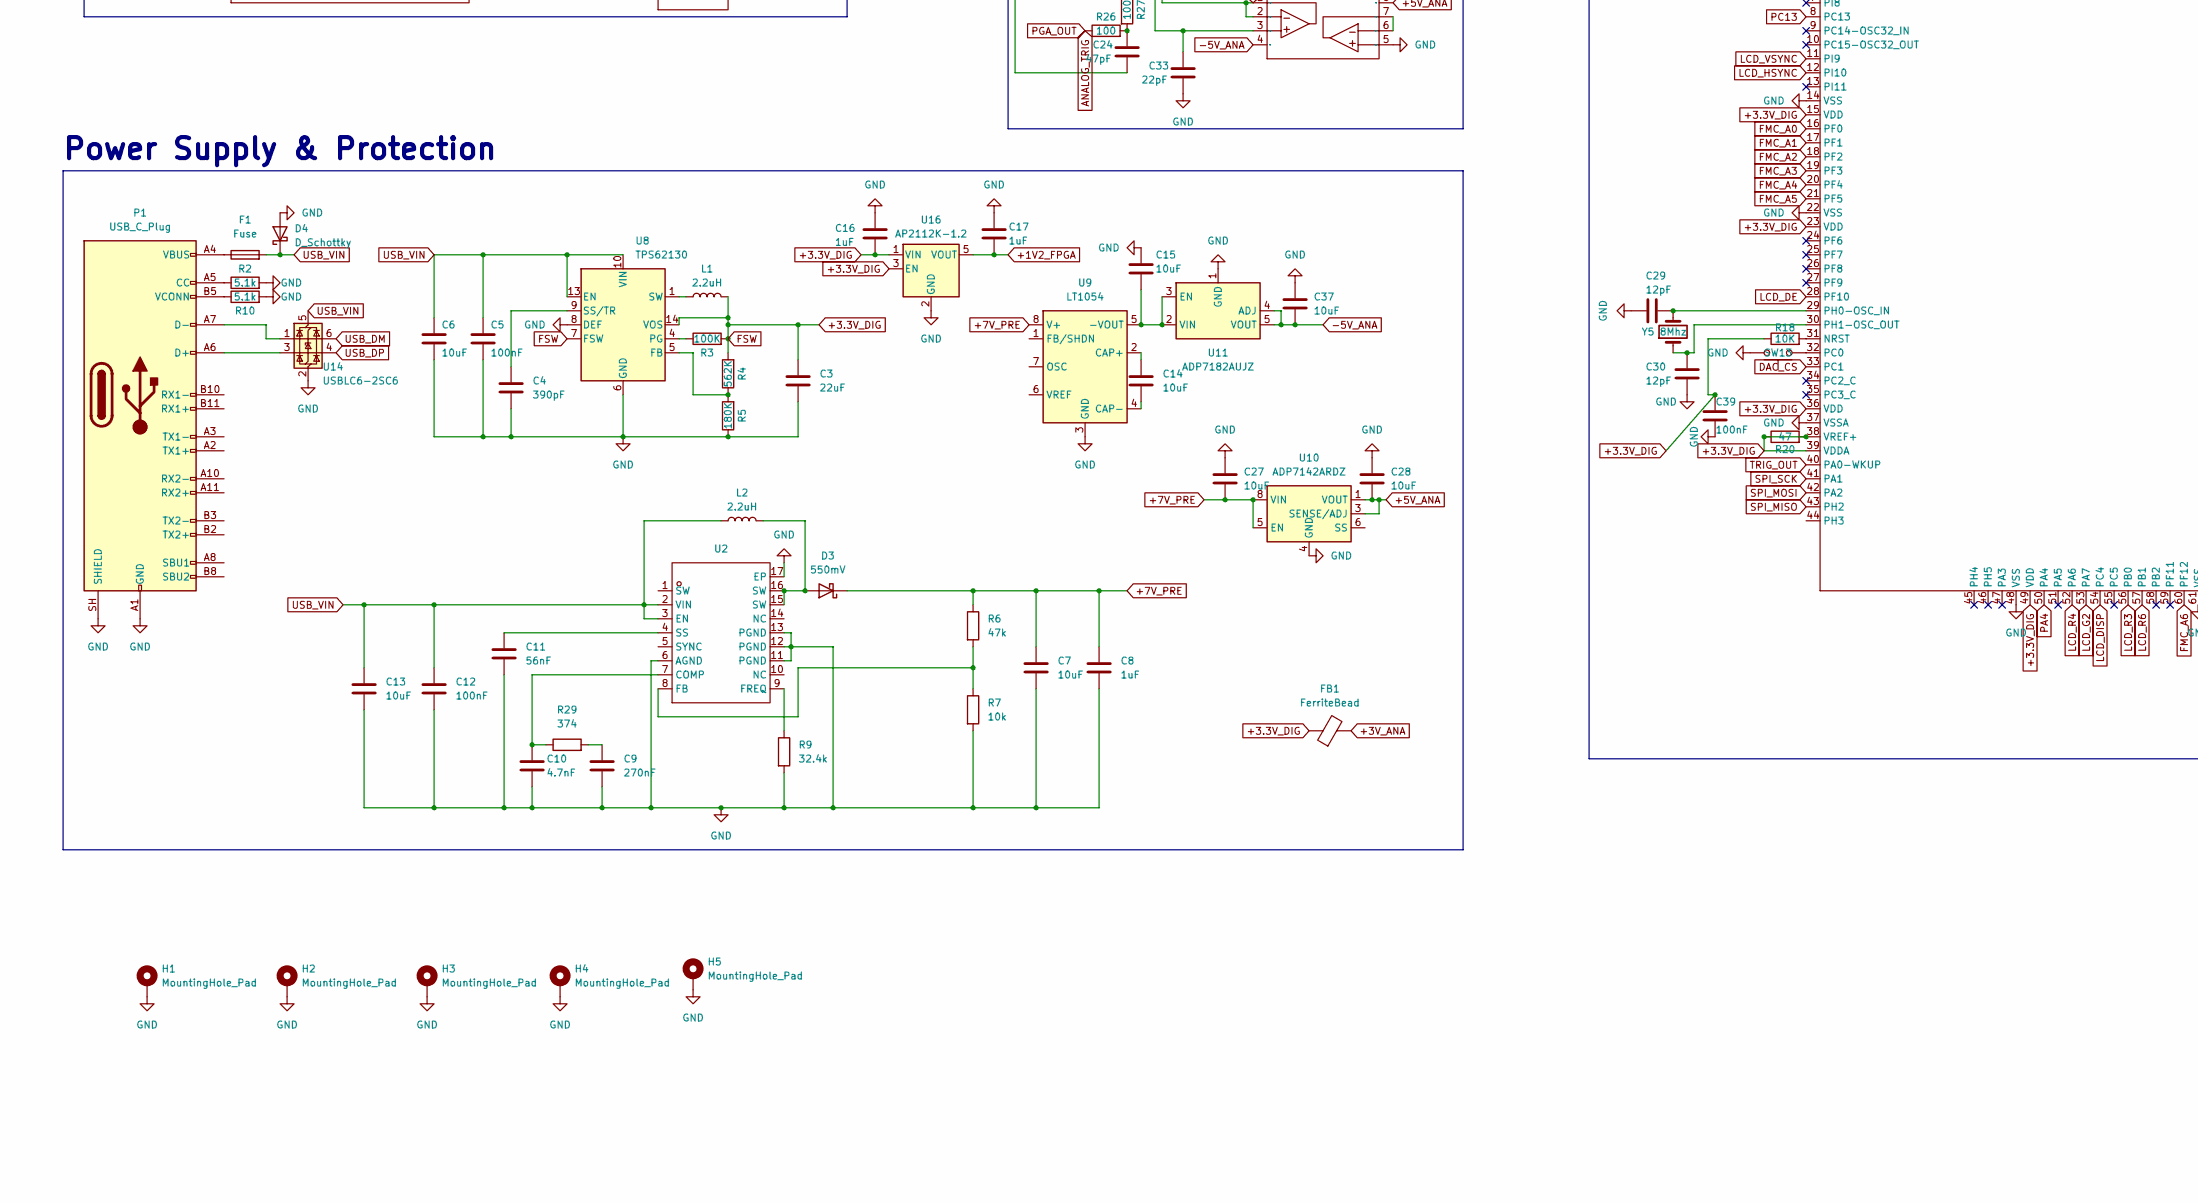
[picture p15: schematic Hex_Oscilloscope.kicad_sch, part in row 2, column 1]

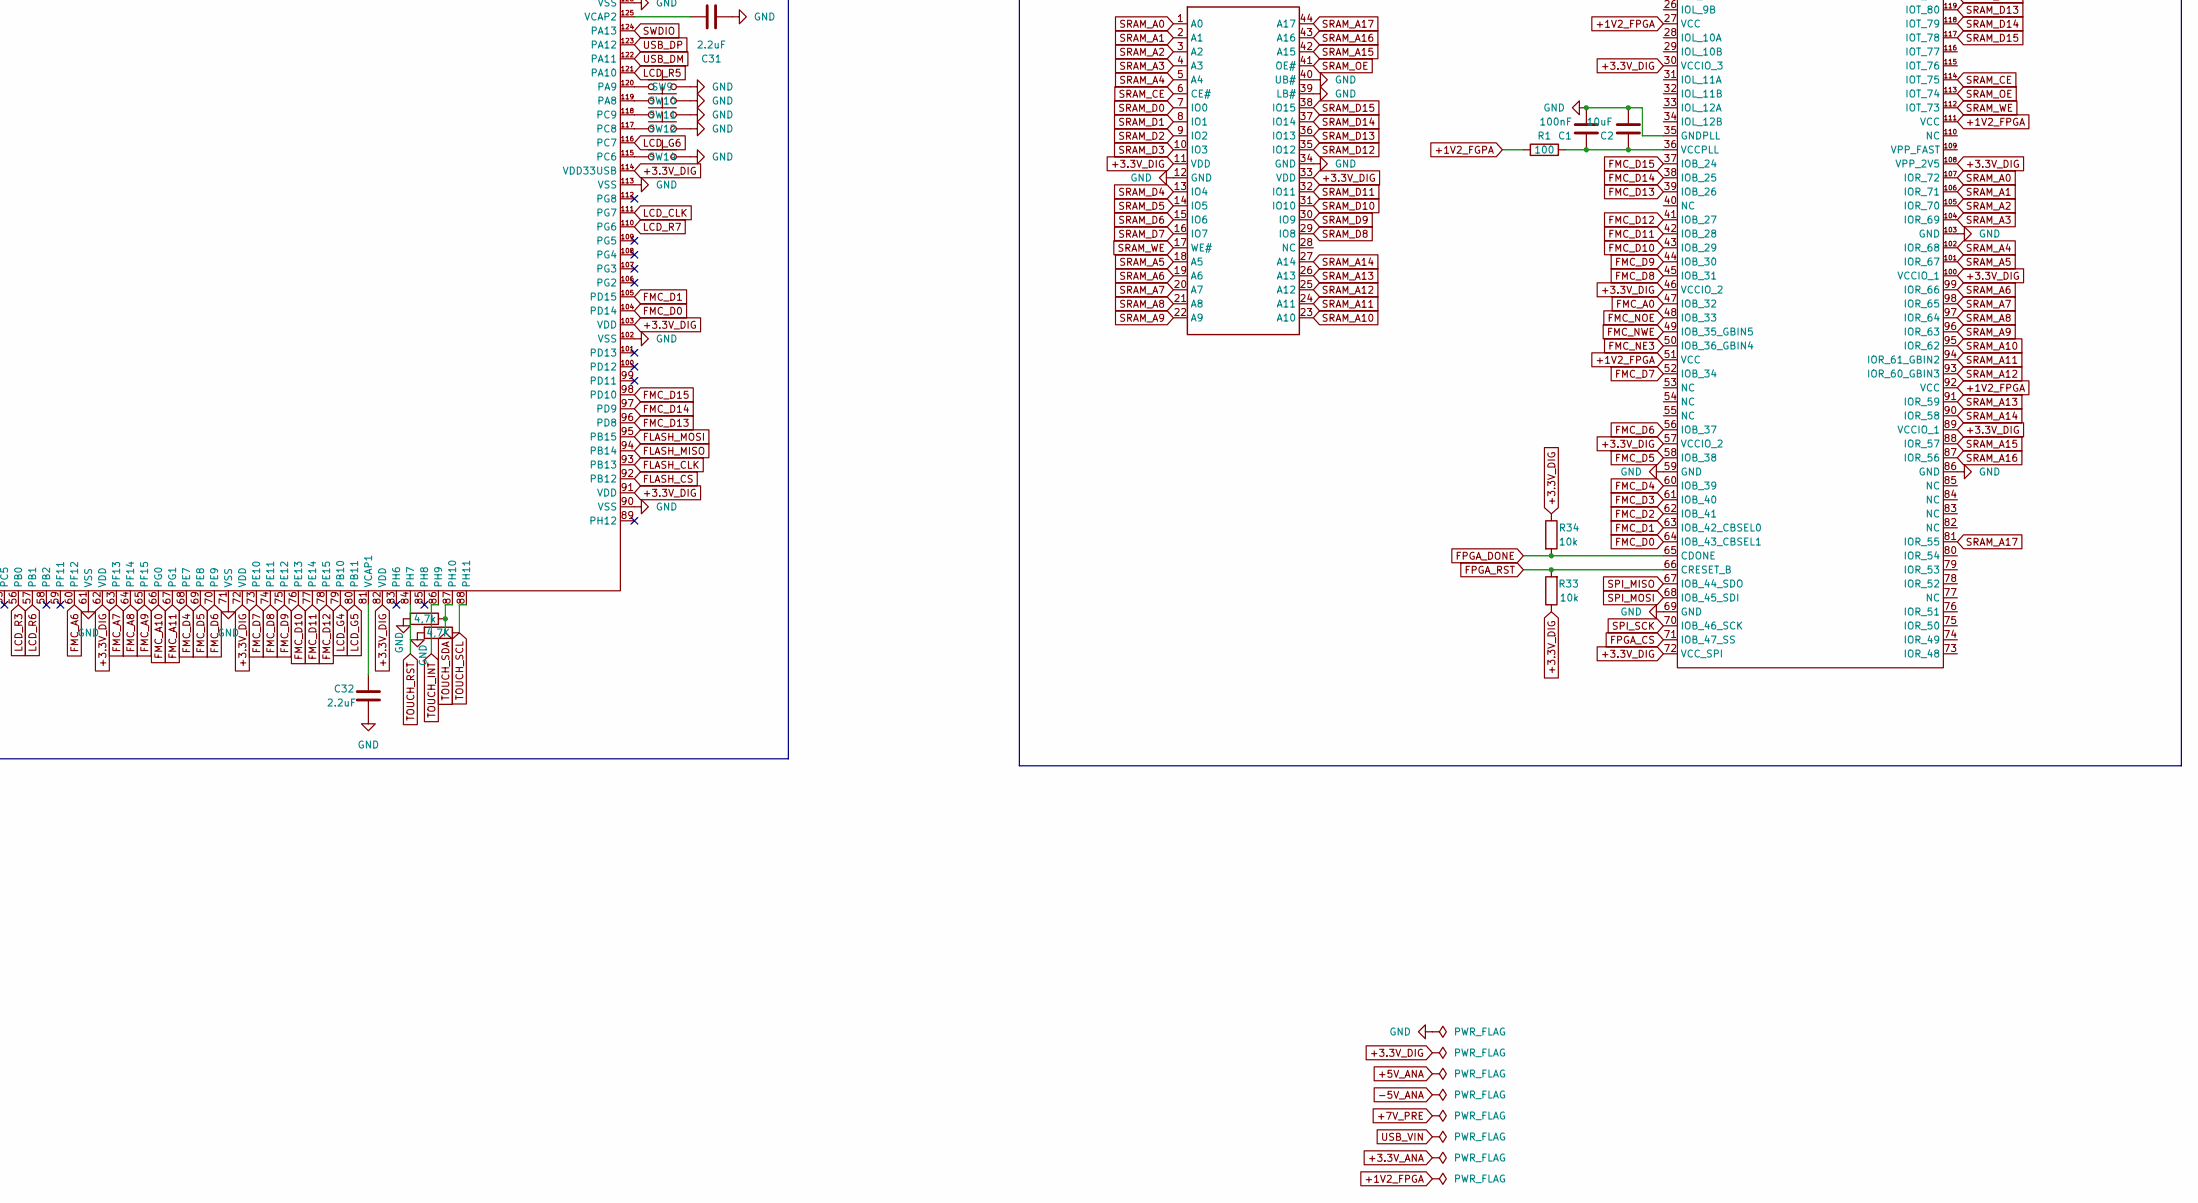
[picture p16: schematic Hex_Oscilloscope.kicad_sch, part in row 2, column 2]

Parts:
C1, C5, C12, C25, C34, C35, C36, C39: 100nF; C_0805_2012Metric
C2, C6, C13, C14, C15, C26, C27, C28, C37: 10uF; C_0805_2012Metric
C3: 22uF; C_0805_2012Metric
C4: 390pF; C_0805_2012Metric
C7: 10uF; C_1210_3225Metric
C8, C16, C17: 1uF; C_0805_2012Metric
C9: 270nF; C_0805_2012Metric
C10: 4.7nF; C_0805_2012Metric
C11: 56nF; C_0805_2012Metric
C18, C19, C20, C21, C22: 100nF; CP_Elec_4x5.4
C23: 30pF; C_0805_2012Metric
C24: 47pF; C_0805_2012Metric
C29, C30: 12pF; C_0805_2012Metric
C31, C32: 2.2uF; C_0805_2012Metric
C33: 22pF; C_0805_2012Metric
C38: 2.2pF; C_0805_2012Metric
D1: BAV99; SOT-23
D2, D5: BAT54S; SOT-23
D3: 550mV; D_SMA
D4: D_Schottky; D_SMB
F1: Fuse; Fuse_1206_3216Metric
FB1: FerriteBead; L_0805_2012Metric
H1, H2, H3, H4, H5: MountingHole_Pad; MountingHole_3.2mm_M3_Pad
J1: Conn_01x03_Pin; PinHeader_1x03_P2.54mm_Vertical
J2: Conn_Coaxial; BNC_Amphenol_031-6575_Horizontal
L1: 2.2uH; L_6.3x6.3_H3
L2: 2.2uH; L_10.4x10.4_H4.8
LCD_CONNECTOR1: Conn_01x40_Socket; Hirose_FH12-40S-0.5SH_1x40-1MP_P0.50mm_Horizontal
P1: USB_C_Plug; USB_C_Receptacle_GCT_USB4110
R1, R21, R26, R27: 100; R_0805_2012Metric
R2, R10: 5.1k; R_0805_2012Metric
R3: 100K; R_0805_2012Metric
R4: 562K; R_0805_2012Metric
R5: 180K; R_0805_2012Metric
R6: 47k; R_0805_2012Metric
R7, R13, R14, R19, R23, R25, R32, R33, R34: 10k; R_0805_2012Metric
R8, R15, R22: 1k; R_0805_2012Metric
R9: 32.4k; R_0805_2012Metric
R11: 220; R_0805_2012Metric
R12: 1M; R_0805_2012Metric
R16, R30, R31: 4,7k; R_0805_2012Metric
R17: 4,7K; R_0805_2012Metric
R18: 10K; R_0805_2012Metric
R20: 47; R_0805_2012Metric
R24: 100k; R_0805_2012Metric
R28: 150; R_0805_2012Metric
R29: 374; R_0805_2012Metric
SW1, SW2: RotaryEncoder_Switch; RotaryEncoder_Alps_EC11E-Switch_Vertical_H20mm
SW9, SW10, SW11, SW12, SW13, SW14: SW_Push; SW_SPST_B3U-1000P
TOUCH_CONNECTOR1: Conn_01x04_Socket; Molex_200528-0040_1x04-1MP_P1.00mm_Horizontal
U1: MCP4922; TSSOP-14_4.4x5mm_P0.65mm
U2: QFN-16_L3.0-W3.0-P0.50-BL-EP1.7; Manufacturer Part TPS55340QRTETQ1; LCSC Part Name 升压型 5.25A 2.9V~38V
U3: TLV3501AID; SOIC-8_3.9x4.9mm_P1.27mm
U4: TQFP-144_L20.0-W20.0-P0.50-LS22.0-BL; Manufacturer Part ICE40HX4K-TQ144; LCSC Part Name 超低功耗、非易失FPGA
U5: TSSOP-24_L7.8-W4.4-P0.65-LS6.4-BL; Manufacturer Part ADC08100CIMTC; LCSC Part Name 8 位 100MSPS 1.3mW/MSPS 模数转换器(ADC)
U6: W25Q128JVP; WSON-8-1EP_6x5mm_P1.27mm_EP3.4x4.3mm
U7: LQFP-176_L24.0-W24.0-P0.50-LS26.0-BL; Manufacturer Part STM32H743IIT6; LCSC Part Name 带DSP和DP-FPU的高性能ARM Cortex-M7 MCU，具有2 MB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
U8: TPS62130; VQFN-16-1EP_3x3mm_P0.5mm_EP1.68x1.68mm_ThermalVias
U9: LT1054; SOIC-8_3.9x4.9mm_P1.27mm
U10: ADP7142ARDZ; SOIC-8-1EP_3.9x4.9mm_P1.27mm_EP2.29x3mm
U11: ADP7182AUJZ; TSOT-23-5
U13: IS61WV25616BLL-10TLI; TSOP-44_L18.4-W10.2-P0.80-LS11.8-BL; Manufacturer Part IS61WV25616BLL-10TLI; LCSC Part Name 256KX16高速异步CMOS静态RAM
U14: USBLC6-2SC6; SOT-23-6
U15: ADA4817-1ARD; SOIC-8-1EP_3.9x4.9mm_P1.27mm_EP2.29x3mm
U16: AP2112K-1.2; SOT-23-5
U17: SOP-8_L4.9-W3.9-P1.27-LS6.0-TL; Manufacturer Part OPA820IDR; LCSC Part Name OPA820IDR
U18: TSSOP-14_L5.0-W4.4-P0.65-LS6.4-BL; Manufacturer Part ADG1204YRUZ; LCSC Part Name 低电容、低电荷注入±15 V/+12 V, 4:1 iCMOS多路复用器
U19: SOP-8_L4.9-W3.9-P1.27-LS6.0-BL; Manufacturer Part AD8058ARZ; LCSC Part Name 低成本、高性能电压反馈型325 MHz放大器
Y1: CXO_DIP8; Oscillator_DIP-8
Y5: 8Mhz; Crystal_SMD_3225-4Pin_3.2x2.5mm

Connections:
+1V2_FGPA: R1.1
+1V2_FPGA: C17.2, U4.27 (VCC), U4.51 (VCC), U4.92 (VCC), U4.111 (VCC), U16.5 (VOUT)
+3.3V_ANA: D2.2 (K), D5.2 (K), R28.1, U1.11 (VrefB), U1.13 (VrefA), U3.7 (V+), U3.8 (SHDN), U5.1 (VA), U5.4 (VA), U5.12 (VA)
+3.3V_DIG: C3.1, C16.2, C18.1, C19.1, C20.1, C21.1, C22.1, C25.1, C39.1, FB1.1, L1.2, LCD_CONNECTOR1.2, LCD_CONNECTOR1.3, LCD_CONNECTOR1.4, R3.2, R4.2, R13.1, R14.1, R18.1, R19.1, R20.1, R20.2, R30.1, R31.1, R33.1, R34.1, U1.1 (Vdd), U1.9 (~SHDN), U4.6 (VCCIO_3), U4.30 (VCCIO_3), U4.46 (VCCIO_2), U4.57 (VCCIO_2), U4.72 (VCC_SPI), U4.89 (VCCIO_1), U4.100 (VCCIO_1), U4.108 (VPP_2V5), U4.123 (VCCIO_0), U4.133 (VCCIO_0), U5.18 (DR_VD), U6.8 (VCC), U7.6 (VBAT), U7.15 (VDD), U7.23 (VDD), U7.36 (VDD), U7.38 (VREF+), U7.39 (VDDA), U7.49 (VDD), U7.62 (VDD), U7.72 (VDD), U7.82 (VDD), U7.91 (VDD), U7.103 (VDD), U7.114 (VDD33USB), U7.127 (VDD), U7.136 (VDD), U7.149 (VDD), U7.159 (VDD), U7.172 (VDD), U8.7 (FSW), U8.14 (VOS), U13.11 (VDD), U13.33 (VDD), U16.1 (VIN), U16.3 (EN), U18.2 (EN), Y1.1 (EN), Y1.8 (Vcc)
+3V_ANA: FB1.2
+5V_ANA: C28.2, D1.2 (A), U10.1 (VOUT), U10.2 (VOUT), U10.3 (SENSE/ADJ), U15.7 (+V_{S}), U15.8 (~PD), U17.7 (+Vs), U18.12 (VDD), U19.8 (VS+)
+7V_PRE: C7.1, C8.1, C27.2, D3.1 (K), R6.1, U9.8 (V+), U10.5 (EN), U10.7 (VIN), U10.8 (VIN)
-5V_ANA: C37.2, D1.1 (K), U11.4 (ADJ), U11.5 (VOUT), U15.4 (-V_{S}), U15.9 (EP), U17.4 (-Vs), U18.3 (VSS), U19.4 (VS-)
ADC_0: U4.1 (IOL_1A), U5.22 (D0)
ADC_1: U4.2 (IOL_1B), U5.21 (D1)
ADC_2: U4.3 (IOL_2A), U5.20 (D2)
ADC_3: U4.4 (IOL_2B), U5.19 (D3)
ADC_4: U4.7 (IOL_3A), U5.16 (D4)
ADC_5: U4.8 (IOL_3B), U5.15 (D5)
ADC_6: U4.9 (IOL_4A), U5.14 (D6)
ADC_7: U4.10 (IOL_4B), U5.13 (D7)
ADC_CLK: U4.129 (IOT_85_GBIN0), U5.24 (CLK), Y1.5 (OUT)
ANALOG_TRIG: D5.3 (COM), R8.1, R15.1, R26.1, U17.6 (Output)
BOOT0: R32.2, U7.166 (BOOT0)
BUF_OUT: U15.2 (-), U15.6, U17.3 (NoninvertingInput)
CLEAN_SIGNAL: C24.2, D2.3 (COM), U5.6 (VIN), U19.1 (OUT1), U19.2 (IN1-)
DAC_CS: U1.3 (~CS), U7.33 (PC1)
FLASH_CLK: U6.6 (CLK), U7.93 (PB13)
FLASH_CS: U6.1 (~CS), U7.92 (PB12)
FLASH_MISO: U6.2 (DO/IO_{1}), U7.94 (PB14)
FLASH_MOSI: U6.5 (DI/IO_{0}), U7.95 (PB15)
FMC_A0: U4.47 (IOB_32), U7.16 (PF0)
FMC_A1: U7.17 (PF1)
FMC_A2: U7.18 (PF2)
FMC_A3: U7.19 (PF3)
FMC_A4: U7.20 (PF4)
FMC_A5: U7.21 (PF5)
FMC_A6: U7.60 (PF12)
FMC_A7: U7.63 (PF13)
FMC_A8: U7.64 (PF14)
FMC_A9: U7.65 (PF15)
FMC_A10: U7.66 (PG0)
FMC_A11: U7.67 (PG1)
FMC_D0: U4.64 (IOB_43_CBSEL1), U7.104 (PD14)
FMC_D1: U4.63 (IOB_42_CBSEL0), U7.105 (PD15)
FMC_D2: U4.62 (IOB_41), U7.142 (PD0)
FMC_D3: U4.61 (IOB_40), U7.143 (PD1)
FMC_D4: U4.60 (IOB_39), U7.68 (PE7)
FMC_D5: U4.58 (IOB_38), U7.69 (PE8)
FMC_D6: U4.56 (IOB_37), U7.70 (PE9)
FMC_D7: U4.52 (IOB_34), U7.73 (PE10)
FMC_D8: U4.45 (IOB_31), U7.74 (PE11)
FMC_D9: U4.44 (IOB_30), U7.75 (PE12)
FMC_D10: U4.43 (IOB_29), U7.76 (PE13)
FMC_D11: U4.42 (IOB_28), U7.77 (PE14)
FMC_D12: U4.41 (IOB_27), U7.78 (PE15)
FMC_D13: U4.39 (IOB_26), U7.96 (PD8)
FMC_D14: U4.38 (IOB_25), U7.97 (PD9)
FMC_D15: U4.37 (IOB_24), U7.98 (PD10)
FMC_NE3: U4.50 (IOB_36_GBIN4), U7.151 (PD7)
FMC_NOE: U4.48 (IOB_33), U7.146 (PD4)
FMC_NWE: U4.49 (IOB_35_GBIN5), U7.147 (PD5)
FPGA_CS: U4.71 (IOB_47_SS), U7.139 (PC10)
FPGA_DONE: R34.2, U4.65 (CDONE), U7.141 (PC12)
FPGA_RST: R33.2, U4.66 (CRESET_B), U7.140 (PC11)
GAIN_A0: U7.150 (PD6), U18.1 (A0)
GAIN_A1: U7.152 (PG9), U18.14 (A1)
LCD_B3: LCD_CONNECTOR1.24, U7.154 (PG11)
LCD_B4: LCD_CONNECTOR1.25, U7.173 (PI4)
LCD_B5: LCD_CONNECTOR1.26, U7.174 (PI5)
LCD_B6: LCD_CONNECTOR1.27, U7.175 (PI6)
LCD_B7: LCD_CONNECTOR1.28, U7.176 (PI7)
LCD_CLK: LCD_CONNECTOR1.36, U7.111 (PG7)
LCD_DE: LCD_CONNECTOR1.34, U7.28 (PF10)
LCD_DISP: LCD_CONNECTOR1.31, U7.54 (PC4)
LCD_G2: LCD_CONNECTOR1.15, U7.53 (PA7)
LCD_G3: LCD_CONNECTOR1.16, U7.153 (PG10)
LCD_G4: LCD_CONNECTOR1.17, U7.79 (PB10)
LCD_G5: LCD_CONNECTOR1.18, U7.80 (PB11)
LCD_G6: LCD_CONNECTOR1.19, U7.116 (PC7)
LCD_G7: LCD_CONNECTOR1.20, U7.134 (PI3)
LCD_HSYNC: LCD_CONNECTOR1.32, U7.12 (PI10)
LCD_R3: LCD_CONNECTOR1.8, U7.56 (PB0)
LCD_R4: LCD_CONNECTOR1.9, U7.52 (PA6)
LCD_R5: LCD_CONNECTOR1.10, U7.121 (PA10)
LCD_R6: LCD_CONNECTOR1.11, U7.57 (PB1)
LCD_R7: LCD_CONNECTOR1.12, U7.110 (PG6)
LCD_VSYNC: LCD_CONNECTOR1.33, U7.11 (PI9)
unnamed: C9.1, R29.2
unnamed: C24.1, R26.2, R27.2
unnamed: D3.2 (A), L2.2, U2.15 (SW), U2.16 (SW)
unnamed: F1.1, P1.A4 (VBUS), P1.A9 (VBUS), P1.B4 (VBUS), P1.B9 (VBUS)
unnamed: J2.1 (In), R11.2
unnamed: L1.1, U8.1 (SW), U8.2 (SW), U8.3 (SW)
unnamed: P1.A5 (CC), R2.1
unnamed: P1.A6 (D+), U14.3 (I/O2)
unnamed: P1.A7 (D-), U14.1 (I/O1)
unnamed: P1.B5 (VCONN), R10.1
unnamed: U1.10 (VB), U3.2 (-)
unnamed: C10.1, R29.1, U2.7 (COMP)
unnamed: R6.2, R7.1, U2.8 (FB)
unnamed: R9.1, U2.9 (FREQ)
unnamed: C11.1, U2.4 (SS)
unnamed: R8.2, U3.3 (+)
unnamed: C1.1, C2.1, R1.2, U4.36 (VCCPLL)
unnamed: C35.2, U5.9 (VRM)
unnamed: C36.2, R28.2, U5.3 (VRT)
unnamed: R14.2, U6.7 (~HOLD/~RESET/IO_{3})
unnamed: R13.2, U6.3 (~WP/IO_{2})
unnamed: R18.2, U7.31 (NRST)
unnamed: SW10.1, U7.119 (PA8)
unnamed: SW9.1, U7.120 (PA9)
unnamed: SW2.B, U7.162 (PB4)
unnamed: SW2.A, U7.163 (PB5)
unnamed: SW1.B, U7.164 (PB6)
unnamed: SW1.A, U7.165 (PB7)
unnamed: SW13.1, U7.32 (PC0)
unnamed: SW14.1, U7.115 (PC6)
unnamed: SW12.1, U7.117 (PC8)
unnamed: SW11.1, U7.118 (PC9)
unnamed: R19.2, U7.171 (PDR_ON)
unnamed: C29.2, U7.29 (PH0-OSC_IN), Y5.2
unnamed: C30.1, U7.30 (PH1-OSC_OUT), Y5.1
unnamed: C32.2, U7.81 (VCAP1)
unnamed: C31.2, U7.125 (VCAP2)
unnamed: R4.1, R5.2, U8.5 (FB)
unnamed: R3.1, U8.4 (PG)
unnamed: C4.1, U8.9 (SS/TR)
unnamed: C14.1, U9.2 (CAP+)
unnamed: C14.2, U9.4 (CAP-)
unnamed: C15.1, U9.5 (-VOUT), U11.2 (VIN), U11.3 (EN)
unnamed: C23.2, D1.3 (K), R11.1, R12.2, U15.3 (+)
unnamed: C38.2, R15.2, R25.1, U17.2 (InvertingInput), U18.6 (D)
unnamed: R21.2, U18.4 (S1)
unnamed: R22.2, U18.5 (S2)
unnamed: R23.2, U18.11 (S3)
unnamed: R24.2, U18.10 (S4)
unnamed: C33.1, R27.1, U19.3 (IN1+)
unnamed: U19.6 (IN2-), U19.7 (OUT2)
OFFSET_DC: R25.2, U1.14 (VA)
PA4: U7.50 (PA4)
PC13: SW1.S1, U7.8 (PC13)
SPI_MISO: U4.67 (IOB_44_SDO), U7.43 (PH2)
SPI_MOSI: U1.5 (SDI), U4.68 (IOB_45_SDI), U7.42 (PA2)
SPI_SCK: U1.4 (SCK), U4.70 (IOB_46_SCK), U7.41 (PA1)
SRAM_A0: U4.107 (IOR_72), U13.1 (A0)
SRAM_A1: U4.106 (IOR_71), U13.2 (A1)
SRAM_A2: U4.105 (IOR_70), U13.3 (A2)
SRAM_A3: U4.104 (IOR_69), U13.4 (A3)
SRAM_A4: U4.102 (IOR_68), U13.5 (A4)
SRAM_A5: U4.101 (IOR_67), U13.18 (A5)
SRAM_A6: U4.99 (IOR_66), U13.19 (A6)
SRAM_A7: U4.98 (IOR_65), U13.20 (A7)
SRAM_A8: U4.97 (IOR_64), U13.21 (A8)
SRAM_A9: U4.96 (IOR_63), U13.22 (A9)
SRAM_A10: U4.95 (IOR_62), U13.23 (A10)
SRAM_A11: U4.94 (IOR_61_GBIN2), U13.24 (A11)
SRAM_A12: U4.93 (IOR_60_GBIN3), U13.25 (A12)
SRAM_A13: U4.91 (IOR_59), U13.26 (A13)
SRAM_A14: U4.90 (IOR_58), U13.27 (A14)
SRAM_A15: U4.88 (IOR_57), U13.42 (A15)
SRAM_A16: U4.87 (IOR_56), U13.43 (A16)
SRAM_A17: U4.81 (IOR_55), U13.44 (A17)
SRAM_CE: U4.114 (IOT_75), U13.6 (CE#)
SRAM_D0: U4.144 (IOT_96), U13.7 (IO0)
SRAM_D1: U4.143 (IOT_95), U13.8 (IO1)
SRAM_D2: U4.142 (IOT_94), U13.9 (IO2)
SRAM_D3: U4.141 (IOT_93), U13.10 (IO3)
SRAM_D4: U4.139 (IOT_92), U13.13 (IO4)
SRAM_D5: U4.138 (IOT_91), U13.14 (IO5)
SRAM_D6: U4.137 (IOT_90), U13.15 (IO6)
SRAM_D7: U4.136 (IOT_89), U13.16 (IO7)
SRAM_D8: U4.135 (IOT_88), U13.29 (IO8)
SRAM_D9: U4.134 (IOT_87), U13.30 (IO9)
SRAM_D10: U4.122 (IOT_83), U13.31 (IO10)
SRAM_D11: U4.121 (IOT_82), U13.32 (IO11)
SRAM_D12: U4.120 (IOT_81), U13.35 (IO12)
SRAM_D13: U4.119 (IOT_80), U13.36 (IO13)
SRAM_D14: U4.118 (IOT_79), U13.37 (IO14)
SRAM_D15: U4.117 (IOT_78), U13.38 (IO15)
SRAM_OE: U4.113 (IOT_74), U13.41 (OE#)
SRAM_WE: U4.112 (IOT_73), U13.17 (WE#)
SWCLK: J1.2, U7.137 (PA14)
SWDIO: J1.1, U7.124 (PA13)
TOUCH_INT: TOUCH_CONNECTOR1.1, U7.86 (PH9)
TOUCH_RST: TOUCH_CONNECTOR1.2, U7.84 (PH7)
TOUCH_SCL: R17.1, R30.2, TOUCH_CONNECTOR1.4, U7.88 (PH11)
TOUCH_SDA: R16.1, R31.2, TOUCH_CONNECTOR1.3, U7.87 (PH10)
TRIG_OUT: U3.6, U4.11 (IOL_5A), U7.40 (PA0-WKUP)
USB_DM: U7.122 (PA11), U14.6 (I/O1)
USB_DP: U7.123 (PA12), U14.4 (I/O2)
USB_VIN: C5.1, C6.1, C12.1, C13.1, C26.1, D4.1 (K), F1.2, L2.1, LCD_CONNECTOR1.39, LCD_CONNECTOR1.40, U2.2 (VIN), U2.3 (EN), U8.10 (VIN), U8.11 (VIN), U8.12 (VIN), U8.13 (EN), U14.5 (VBUS)
VIN_GND: C1.2, C2.2, C3.2, C4.2, C5.2, C6.2, C7.2, C8.2, C9.2, C10.2, C11.2, C12.2, C13.2, C15.2, C16.1, C17.1, C18.2, C19.2, C20.2, C21.2, C22.2, C23.1, C25.2, C26.2, C27.1, C28.1, C29.1, C30.2, C31.1, C32.1, C33.2, C34.1, C34.2, C35.1, C36.1, C37.1, C38.1, C39.2, D2.1 (A), D4.2 (A), D5.1 (A), H1.1 (1_1), H2.1 (1_1), H3.1 (1_1), H4.1 (1_1), H5.1 (1_1), J1.3, J2.2 (Ext), LCD_CONNECTOR1.1, LCD_CONNECTOR1.5, LCD_CONNECTOR1.6, LCD_CONNECTOR1.7, LCD_CONNECTOR1.13, LCD_CONNECTOR1.14, LCD_CONNECTOR1.21, LCD_CONNECTOR1.22, LCD_CONNECTOR1.23, LCD_CONNECTOR1.29, LCD_CONNECTOR1.30, LCD_CONNECTOR1.35, LCD_CONNECTOR1.38, P1.A1 (GND), P1.A12 (GND), P1.B1 (GND), P1.B12 (GND), P1.SH (SHIELD), R2.2, R5.1, R7.2, R9.2, R10.2, R12.1, R16.2, R17.2, R21.1, R22.1, R23.1, R24.1, R32.1, SW1.C, SW1.S2, SW2.C, SW2.S2, SW9.2, SW10.2, SW11.2, SW12.2, SW13.2, SW14.2, U1.8 (~LDAC), U1.12 (Vss), U2.6 (AGND), U2.11 (PGND), U2.12 (PGND), U2.13 (PGND), U2.17 (EP), U3.4 (V-), U4.5 (GND), U4.13 (GND), U4.14 (GND), U4.35 (GNDPLL), U4.59 (GND), U4.69 (GND), U4.86 (GND), U4.103 (GND), U4.132 (GND), U4.140 (GND), U5.2 (AGND), U5.5 (AGND), U5.7 (VIN_GND), U5.8 (AGND), U5.10 (VRB), U5.11 (AGND), U5.17 (DR_GND), U5.23 (PD), U6.4 (GND), U7.14 (VSS), U7.22 (VSS), U7.37 (VSSA), U7.48 (VSS), U7.61 (VSS), U7.71 (VSS), U7.90 (VSS), U7.102 (VSS), U7.113 (VSS), U7.126 (VSS), U7.135 (VSS), U7.148 (VSS), U7.158 (VSS), U8.6 (GND), U8.8 (DEF), U8.15 (GND), U8.16 (GND), U8.17 (GND), U9.3 (GND), U10.4 (GND), U10.9 (GND), U11.1 (GND), U13.12 (GND), U13.34 (GND), U13.39 (LB#), U13.40 (UB#), U14.2 (GND), U16.2 (GND), U18.13 (GND), U19.5 (IN2+), Y1.4 (GND)

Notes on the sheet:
Data acquisition, Clock & Hardware trigger
Anti-Aliasing Filter
Signal Input
MCU
Programmable Gain Amplifier
Memory
Display and touch Connectors
Power Supply & Protection

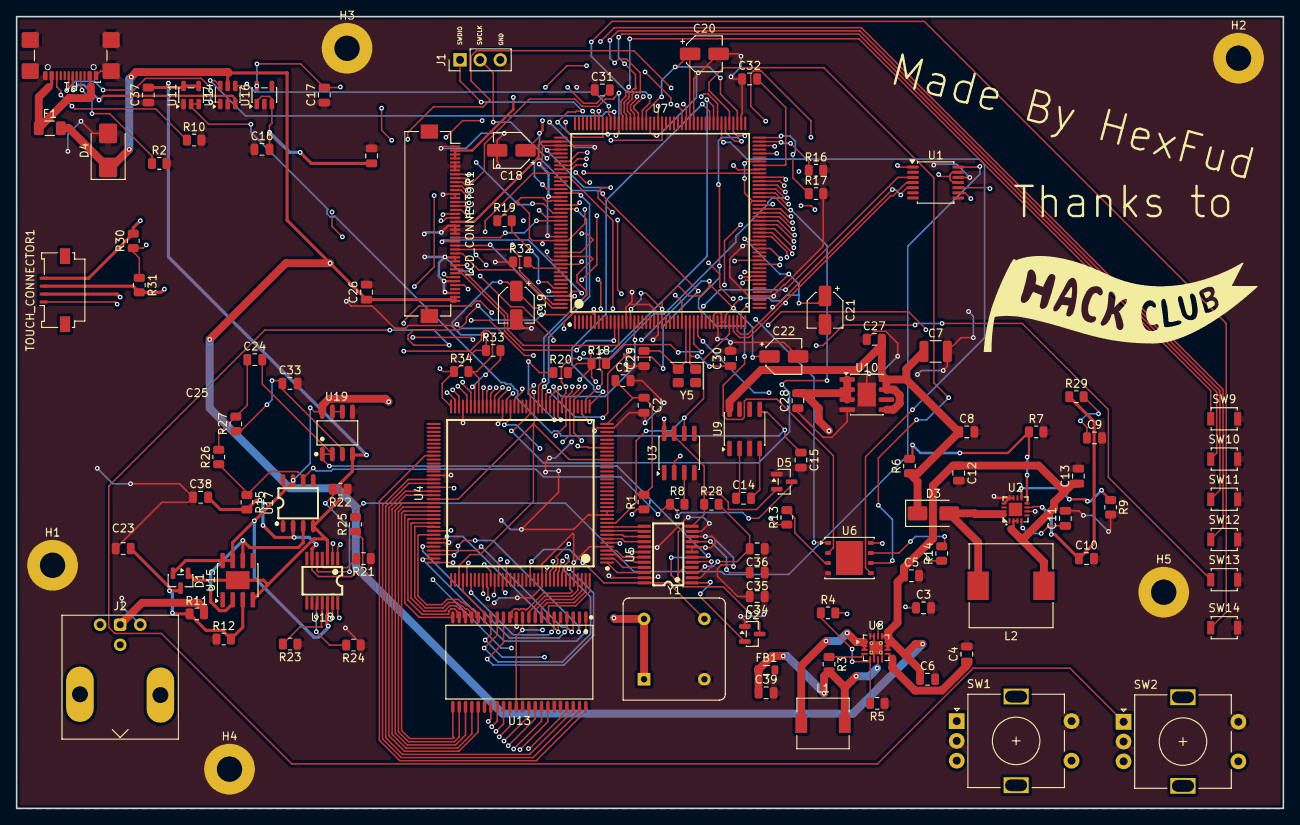
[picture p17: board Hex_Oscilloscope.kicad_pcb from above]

Board: 4 copper layers, 160.0 x 100.0 mm, 120 parts (0 on the bottom side), 174 nets.

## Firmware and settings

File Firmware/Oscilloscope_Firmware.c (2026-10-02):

#include <stdint.h>
#include <string.h>

#define SRAM_BASE_ADDRESS ((uint32_t)0x60000000) 
#define NUM_SAMPLES       1024

void HAL_Init(void) {}
void SystemClock_Config(void) {}
void MX_GPIO_Init(void) {}
void MX_SPI_Init(void) {}
void MX_FMC_Init(void) {}
void MX_LTDC_Init(void) {}
void MX_I2C_Init(void) {}

uint8_t waveform_buffer[NUM_SAMPLES];

typedef enum {
    STATE_INIT,
    STATE_ARM_FPGA,
    STATE_WAIT_TRIGGER,
    STATE_FETCH_DATA,
    STATE_PROCESS_AND_DRAW
} OscState;

OscState currentState = STATE_INIT;

void AFE_SetTriggerLevel(uint16_t millivolts) {
}

void AFE_SetGain(uint8_t scale_index) {
}

void FPGA_ArmTrigger(void) {
}

uint8_t FPGA_IsDataReady(void) {
    return 1;
}

void FetchDataFromSRAM(void) {
    memcpy(waveform_buffer, (uint8_t*)SRAM_BASE_ADDRESS, NUM_SAMPLES);
}

void LCD_DrawWaveform(uint8_t* data) {
}

int main(void) {
    HAL_Init();
    SystemClock_Config();
    
    MX_GPIO_Init();
    MX_SPI_Init();
    MX_FMC_Init();
    MX_LTDC_Init();
    MX_I2C_Init();

    AFE_SetGain(0);
    AFE_SetTriggerLevel(1500);

    while (1) {
        switch (currentState) {
            
            case STATE_INIT:
                currentState = STATE_ARM_FPGA;
                break;

            case STATE_ARM_FPGA:
                FPGA_ArmTrigger();
                currentState = STATE_WAIT_TRIGGER;
                break;

            case STATE_WAIT_TRIGGER:
                if (FPGA_IsDataReady()) {
                    currentState = STATE_FETCH_DATA;
                }
                break;

            case STATE_FETCH_DATA:
                FetchDataFromSRAM();
                currentState = STATE_PROCESS_AND_DRAW;
                break;

            case STATE_PROCESS_AND_DRAW:
                LCD_DrawWaveform(waveform_buffer);
                currentState = STATE_ARM_FPGA;
                break;
        }
    }
}
